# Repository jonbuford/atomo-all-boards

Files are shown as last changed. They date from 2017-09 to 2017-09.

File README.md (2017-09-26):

# atomo-all_boards
This is a collection of PCB designs for microcontroller development boards created for the Atomo line. We are releasing these files and designs to the world prior to our first production run. Any feedback on them is appreciated. 

Some basics:
1. We are releasing the raw design files and not the production silk screen with our commercial logo for Atomo. (We reserve the copyright on the Atomo brand.)
2. Yes, the refdes locations are on the parts for the most part. Earlier versions of the design attempted to keep all of the refdes markers in locations that could be used for silkscreen printing, but this required some very convoluted manual indications of what matches what. The density on these boards is just too high to have a clean 1:1 refdes printing on the boards. For the production silkscreens, we will be creating markings that is only for typical end use features and for major components or functional areas.
3. The 10-pin JTAG headers have been moved to the 26-pin/40-pin headers to reduce cost and to make all boards programmable using a Raspberry Pi or similar. 
4. Updated the 26-pin and 40-pin headers so that the pins are the same configuration for the first 26 pins. The 40-pin header is compatible with the ethernet adapter. 

So, this is the current state of the finished design files. To be added are the backplane and module files. The intent now is to try to move this into a more open development project to keep things growing. If you are interested in contributing, please contact the project.

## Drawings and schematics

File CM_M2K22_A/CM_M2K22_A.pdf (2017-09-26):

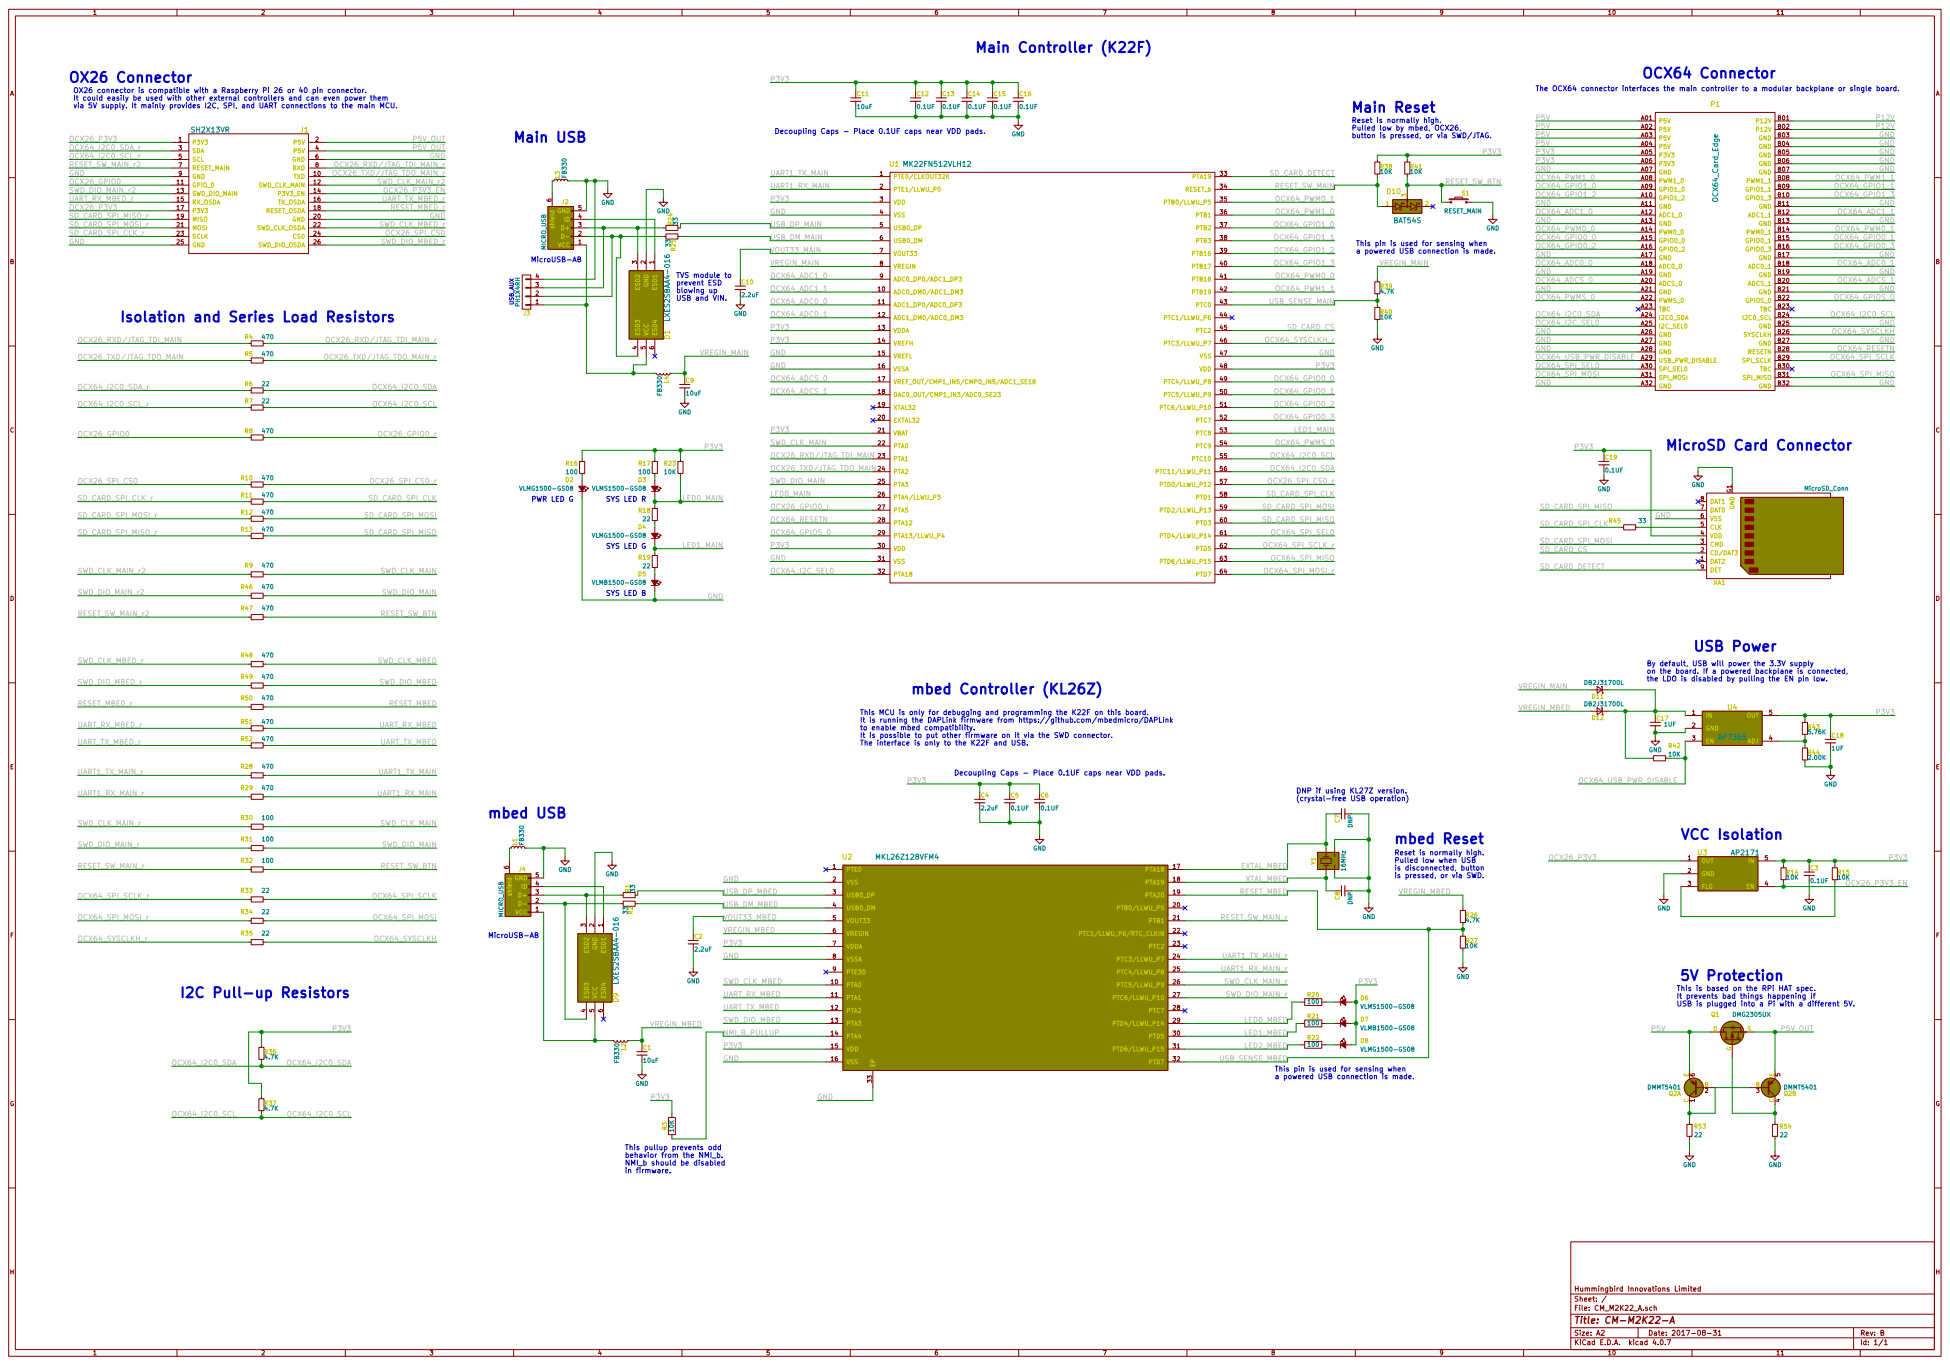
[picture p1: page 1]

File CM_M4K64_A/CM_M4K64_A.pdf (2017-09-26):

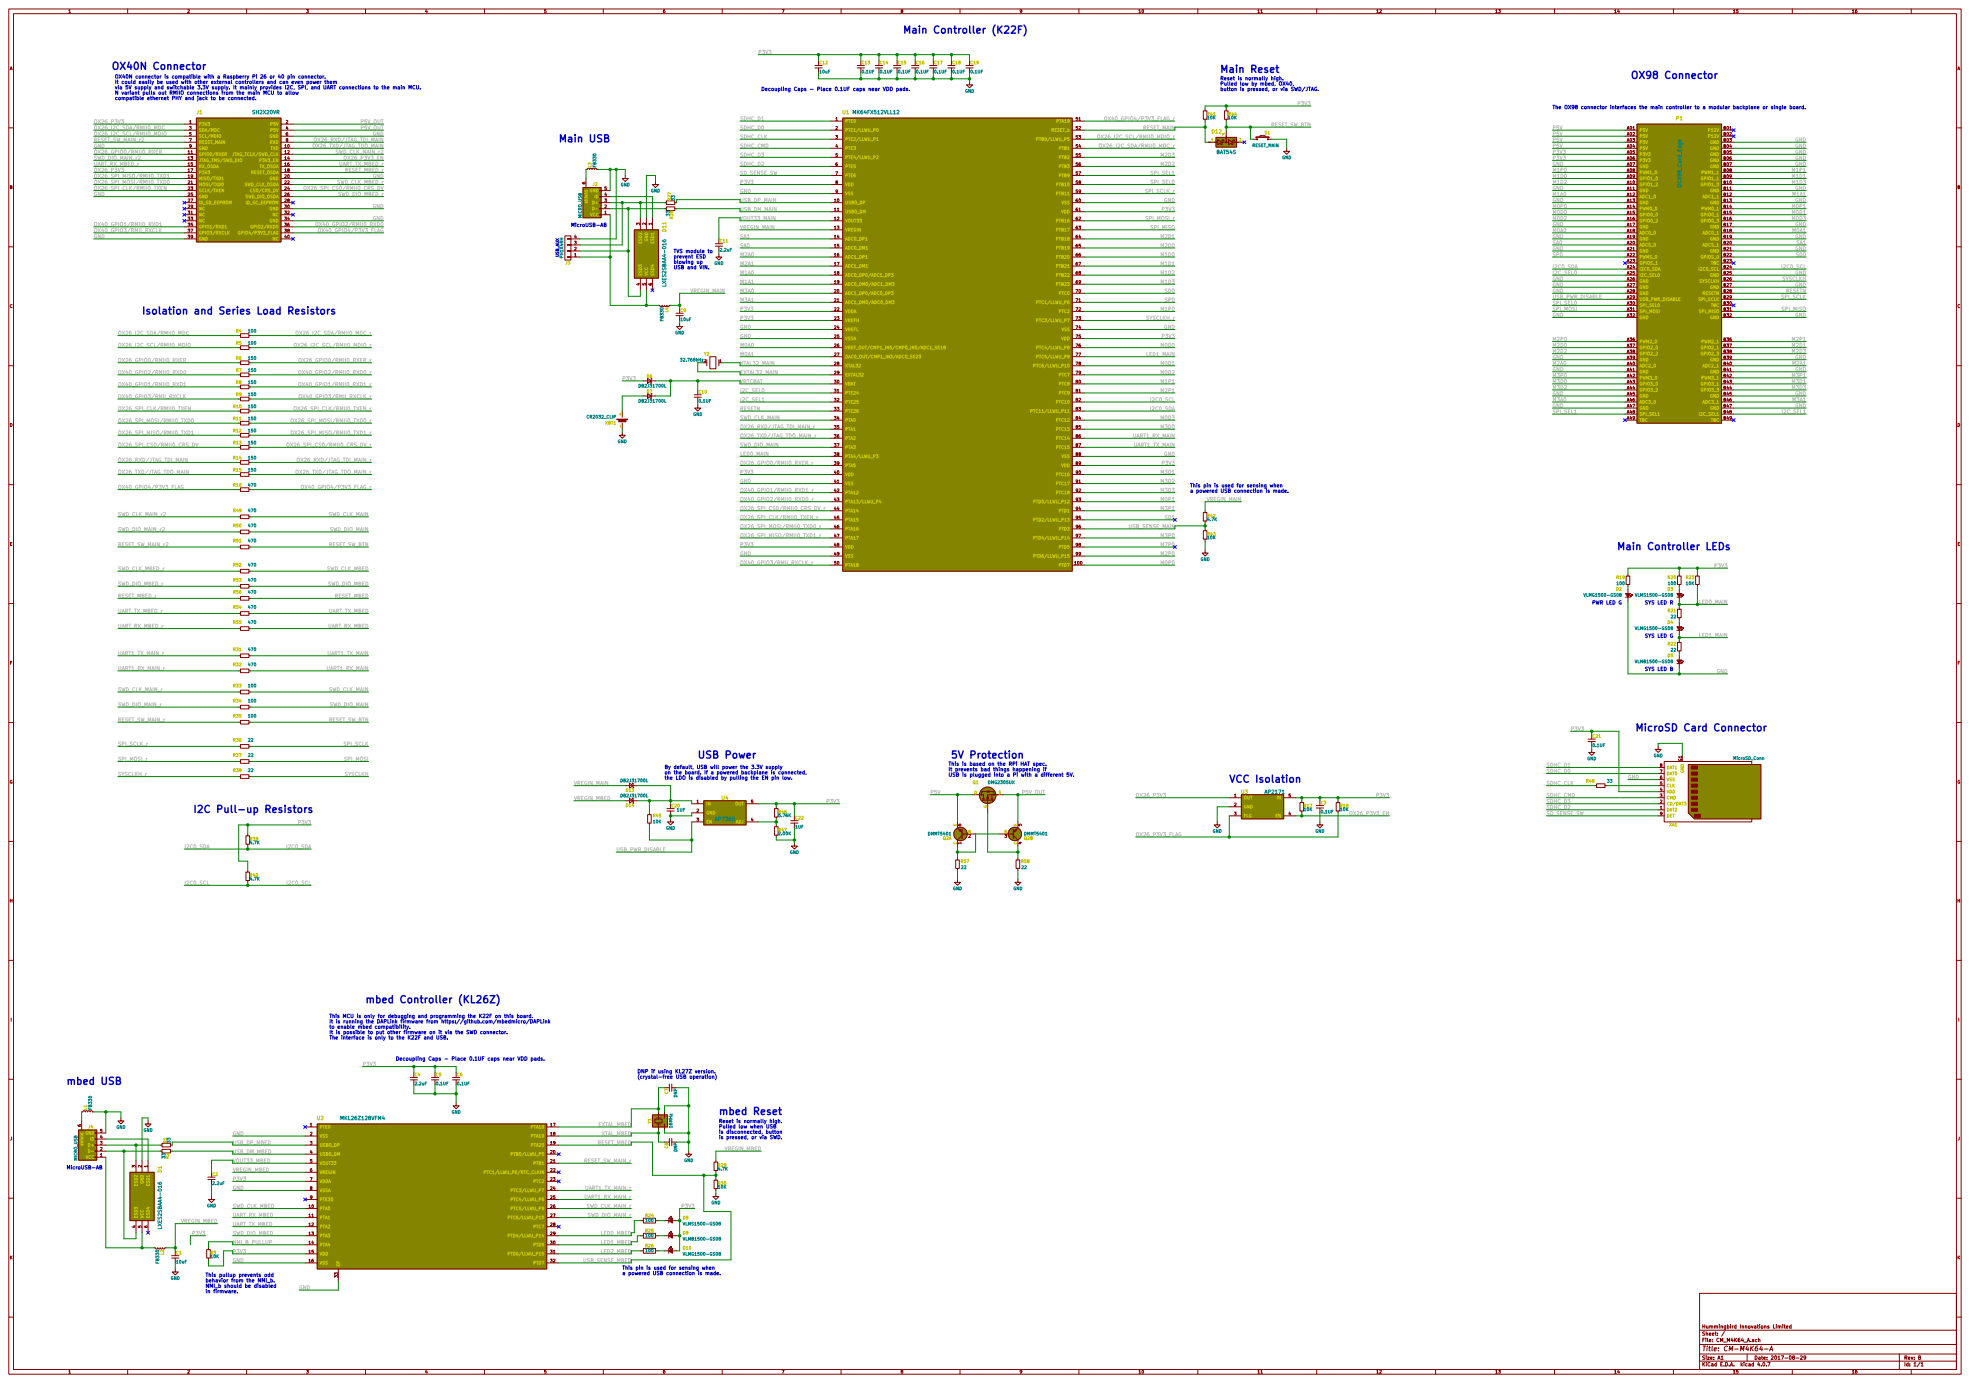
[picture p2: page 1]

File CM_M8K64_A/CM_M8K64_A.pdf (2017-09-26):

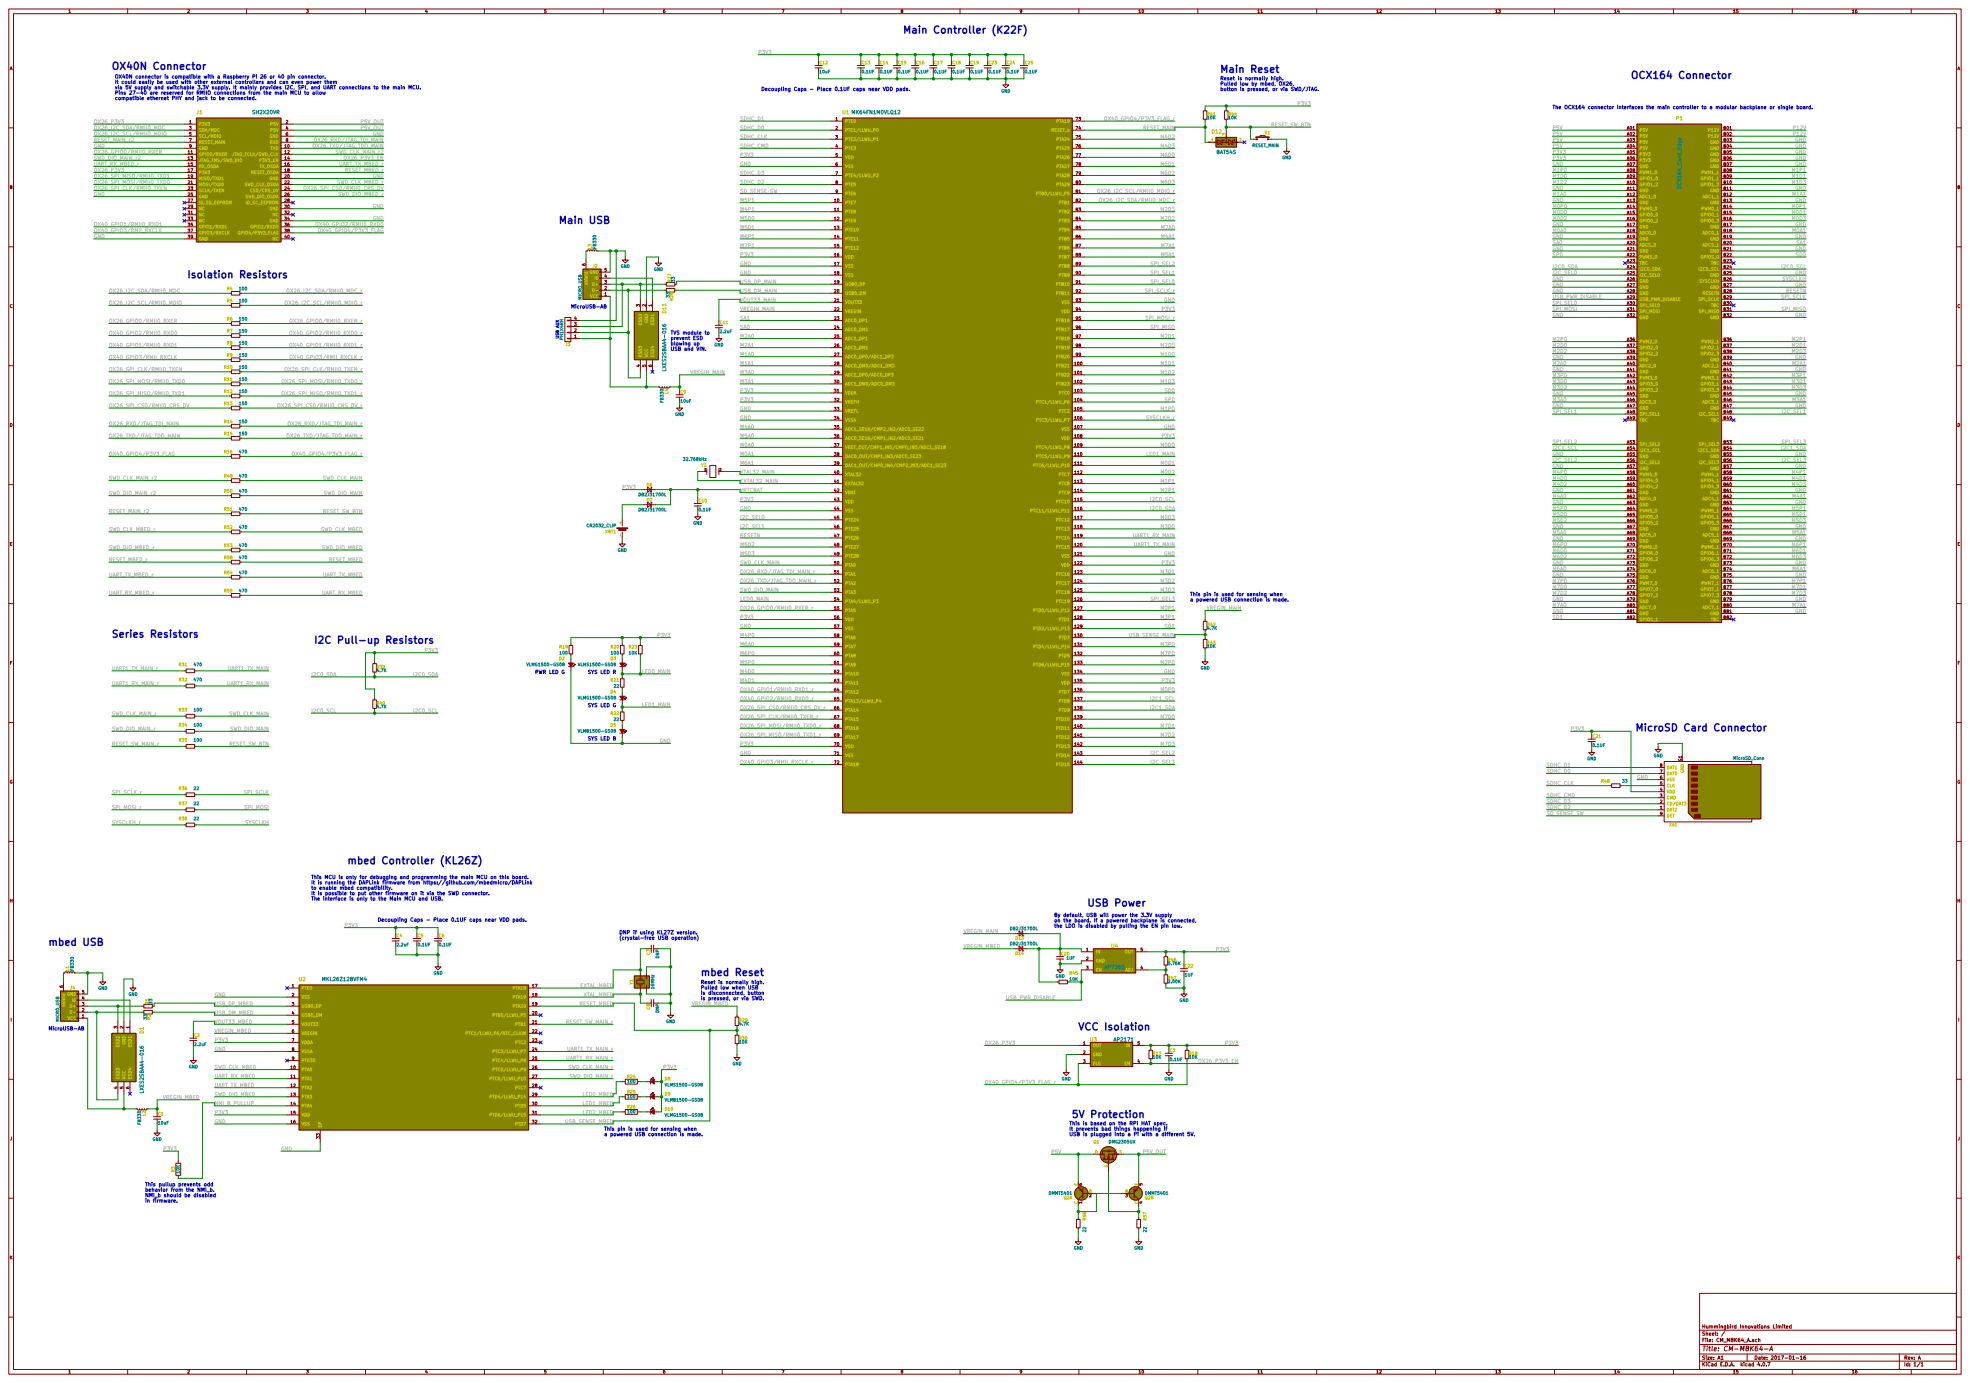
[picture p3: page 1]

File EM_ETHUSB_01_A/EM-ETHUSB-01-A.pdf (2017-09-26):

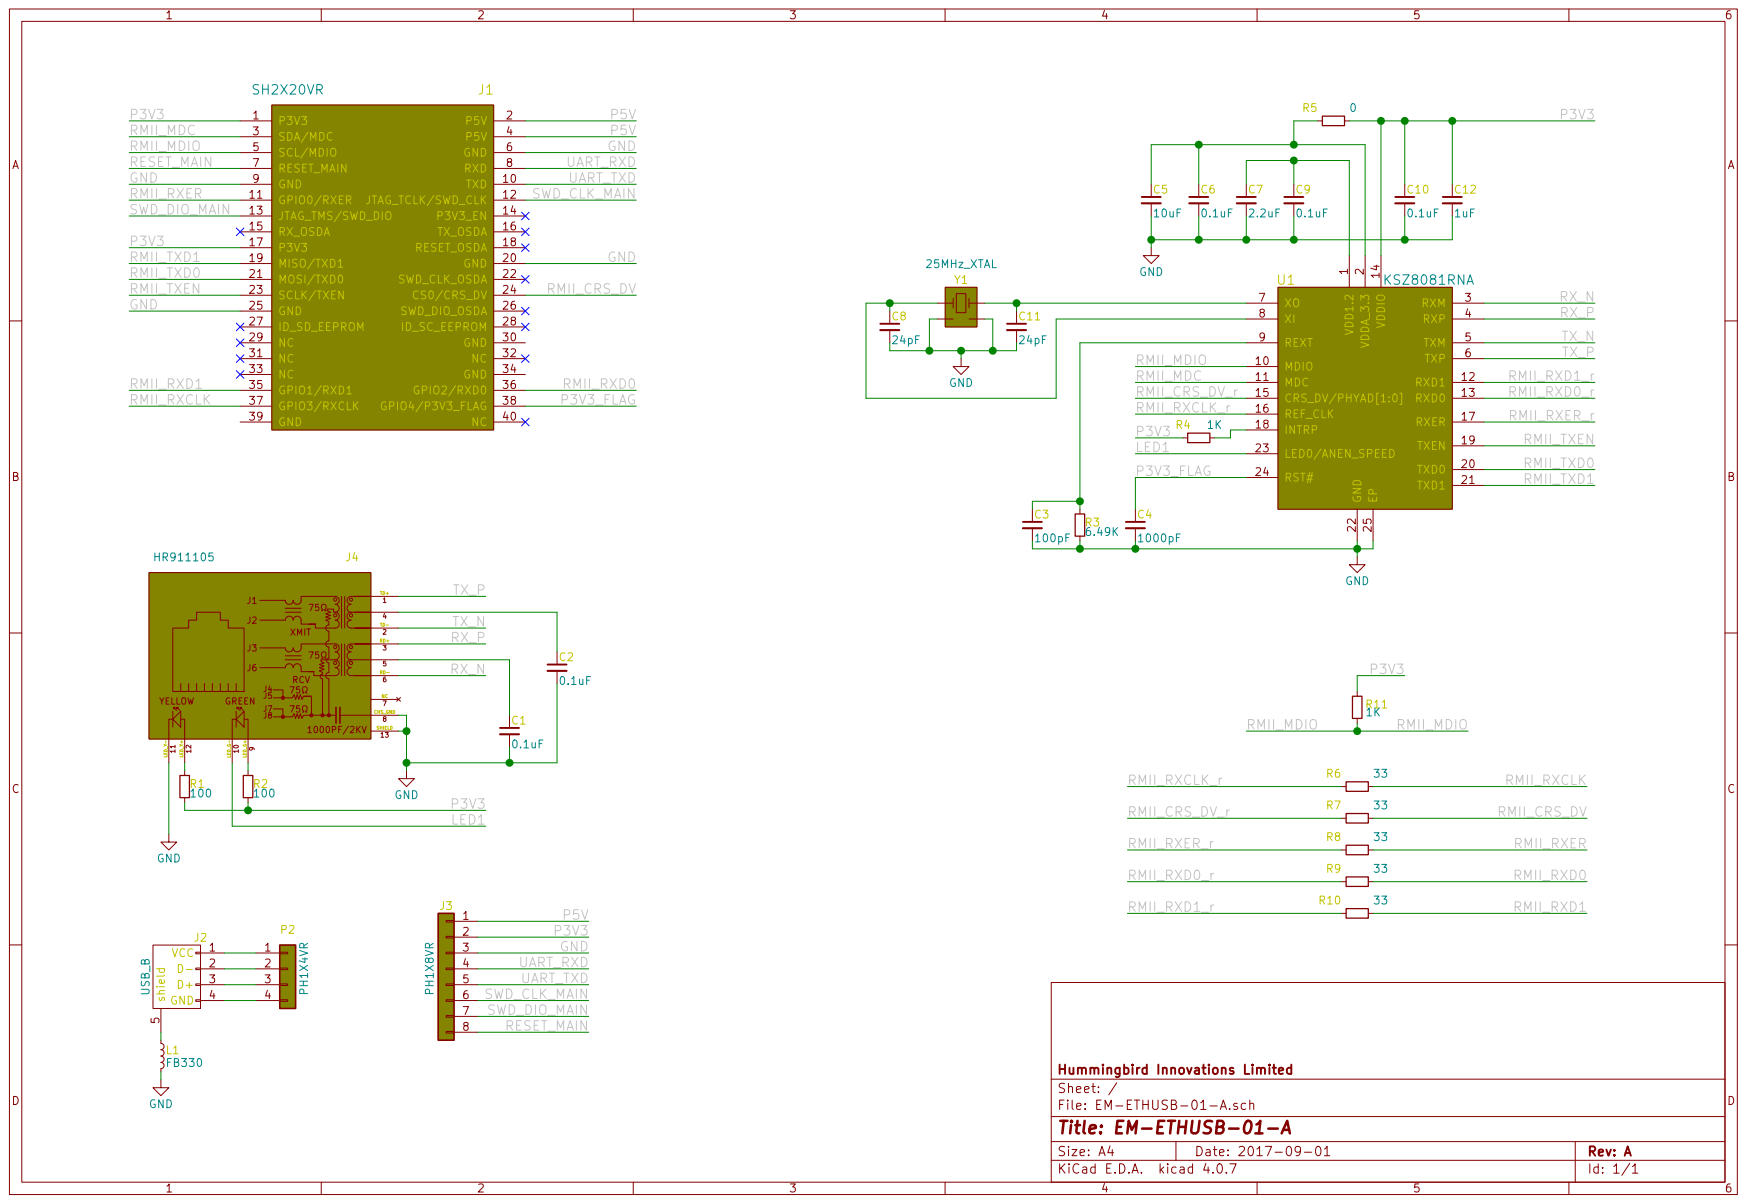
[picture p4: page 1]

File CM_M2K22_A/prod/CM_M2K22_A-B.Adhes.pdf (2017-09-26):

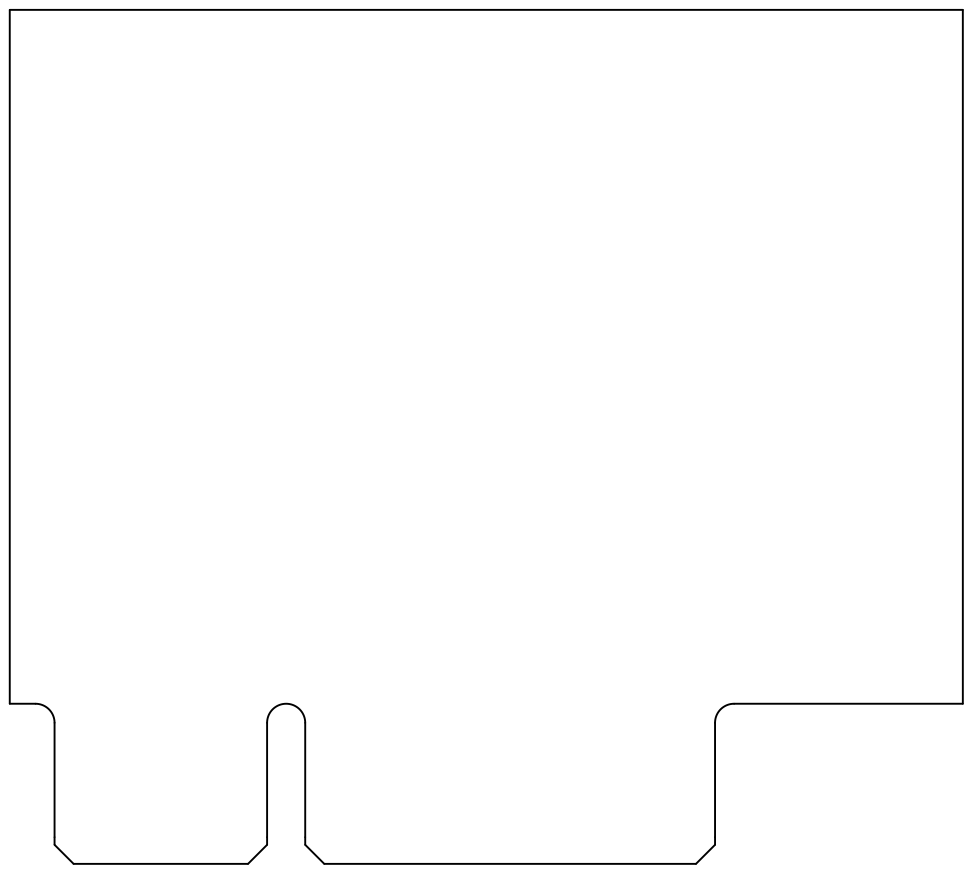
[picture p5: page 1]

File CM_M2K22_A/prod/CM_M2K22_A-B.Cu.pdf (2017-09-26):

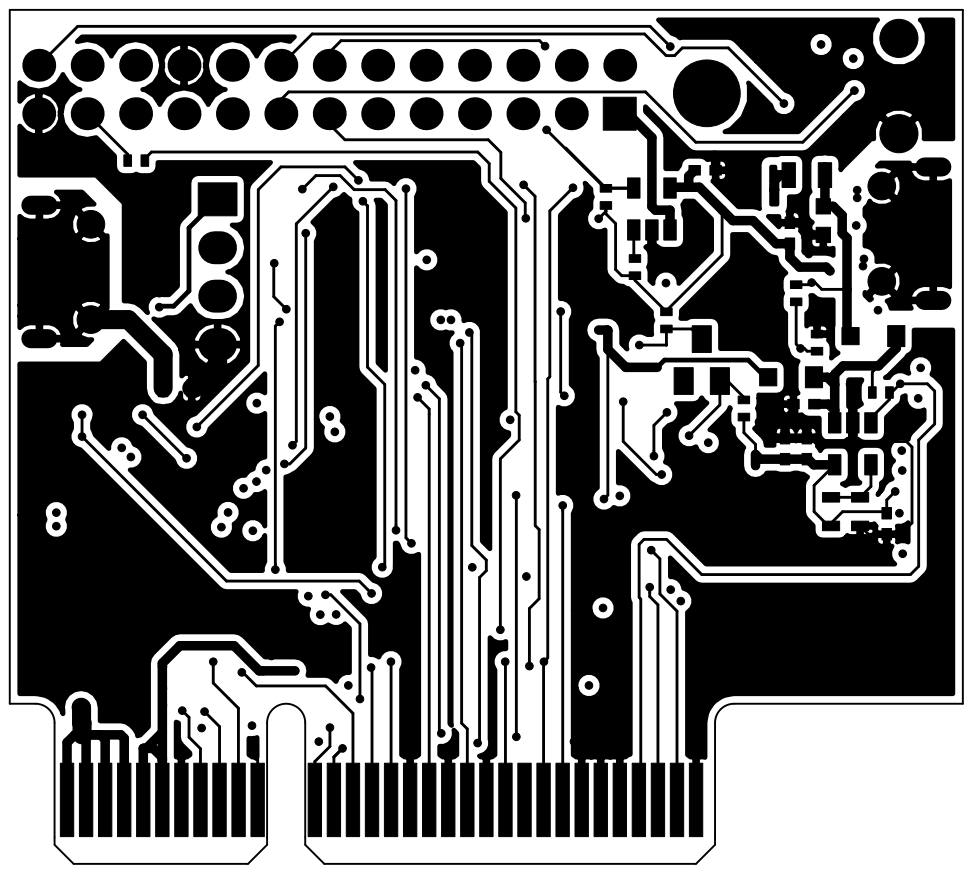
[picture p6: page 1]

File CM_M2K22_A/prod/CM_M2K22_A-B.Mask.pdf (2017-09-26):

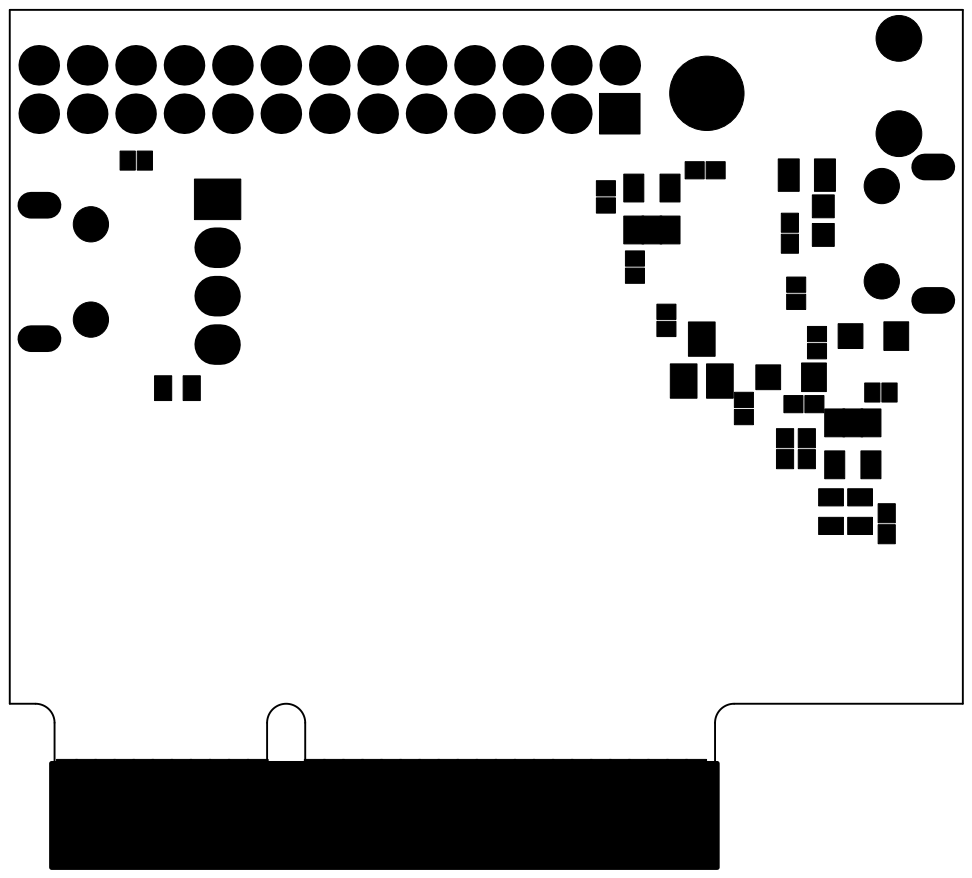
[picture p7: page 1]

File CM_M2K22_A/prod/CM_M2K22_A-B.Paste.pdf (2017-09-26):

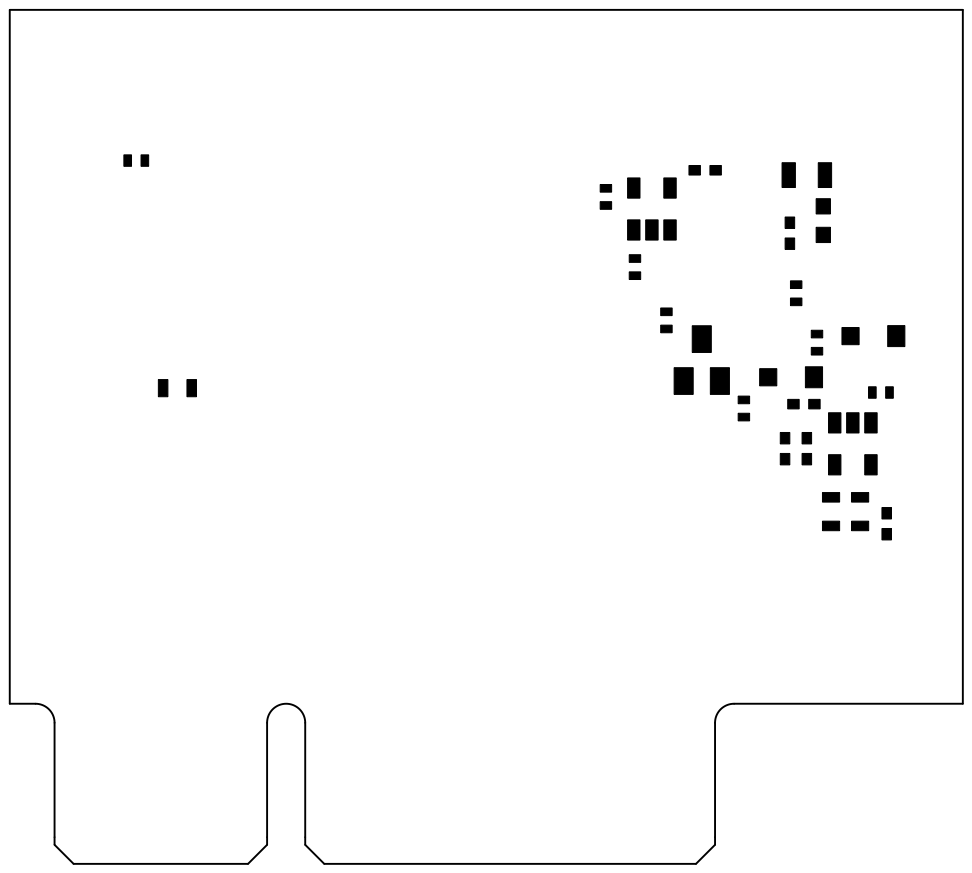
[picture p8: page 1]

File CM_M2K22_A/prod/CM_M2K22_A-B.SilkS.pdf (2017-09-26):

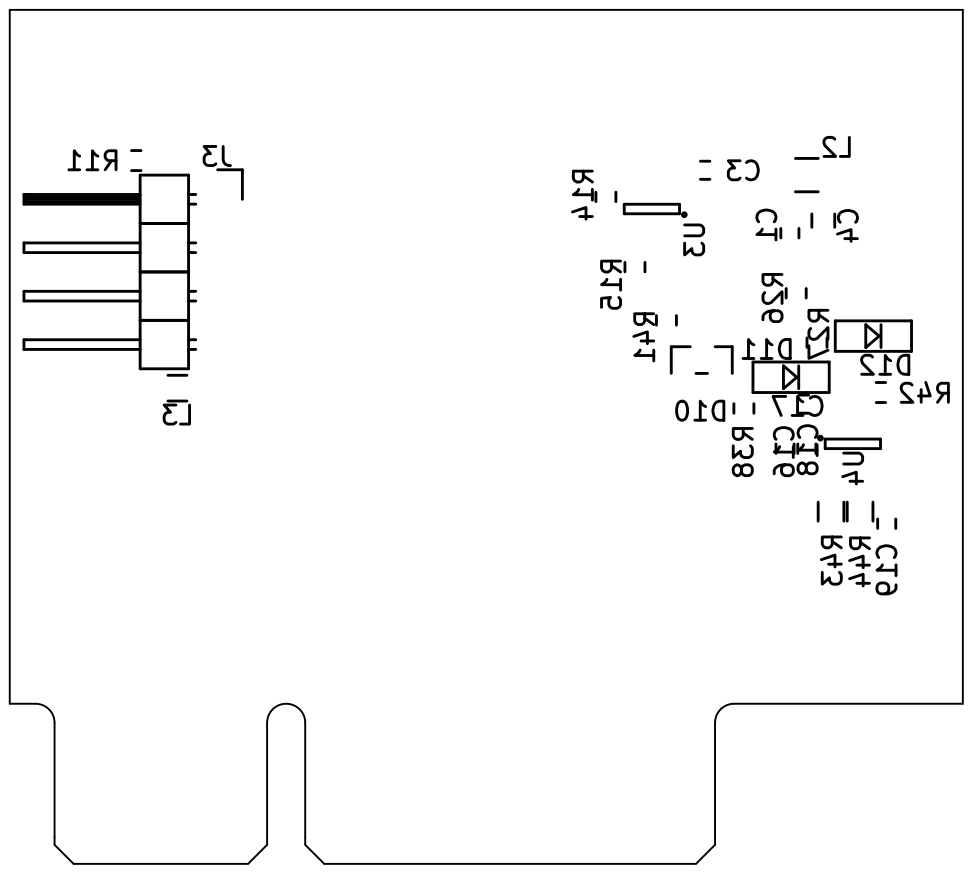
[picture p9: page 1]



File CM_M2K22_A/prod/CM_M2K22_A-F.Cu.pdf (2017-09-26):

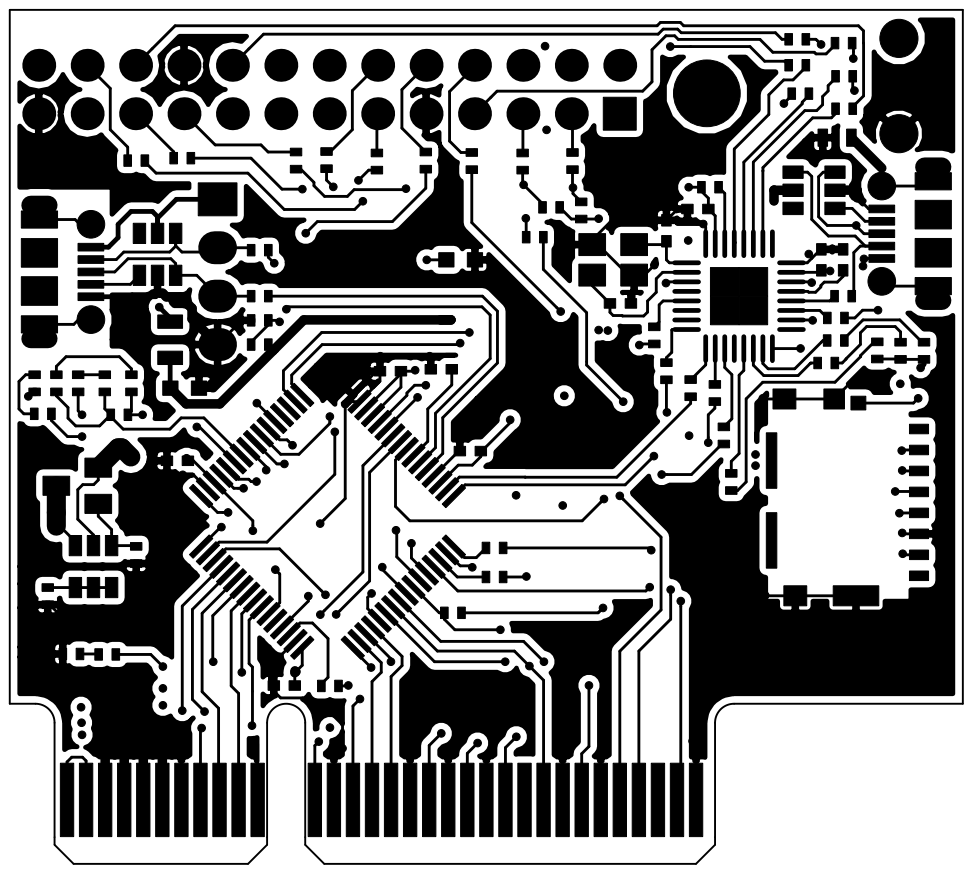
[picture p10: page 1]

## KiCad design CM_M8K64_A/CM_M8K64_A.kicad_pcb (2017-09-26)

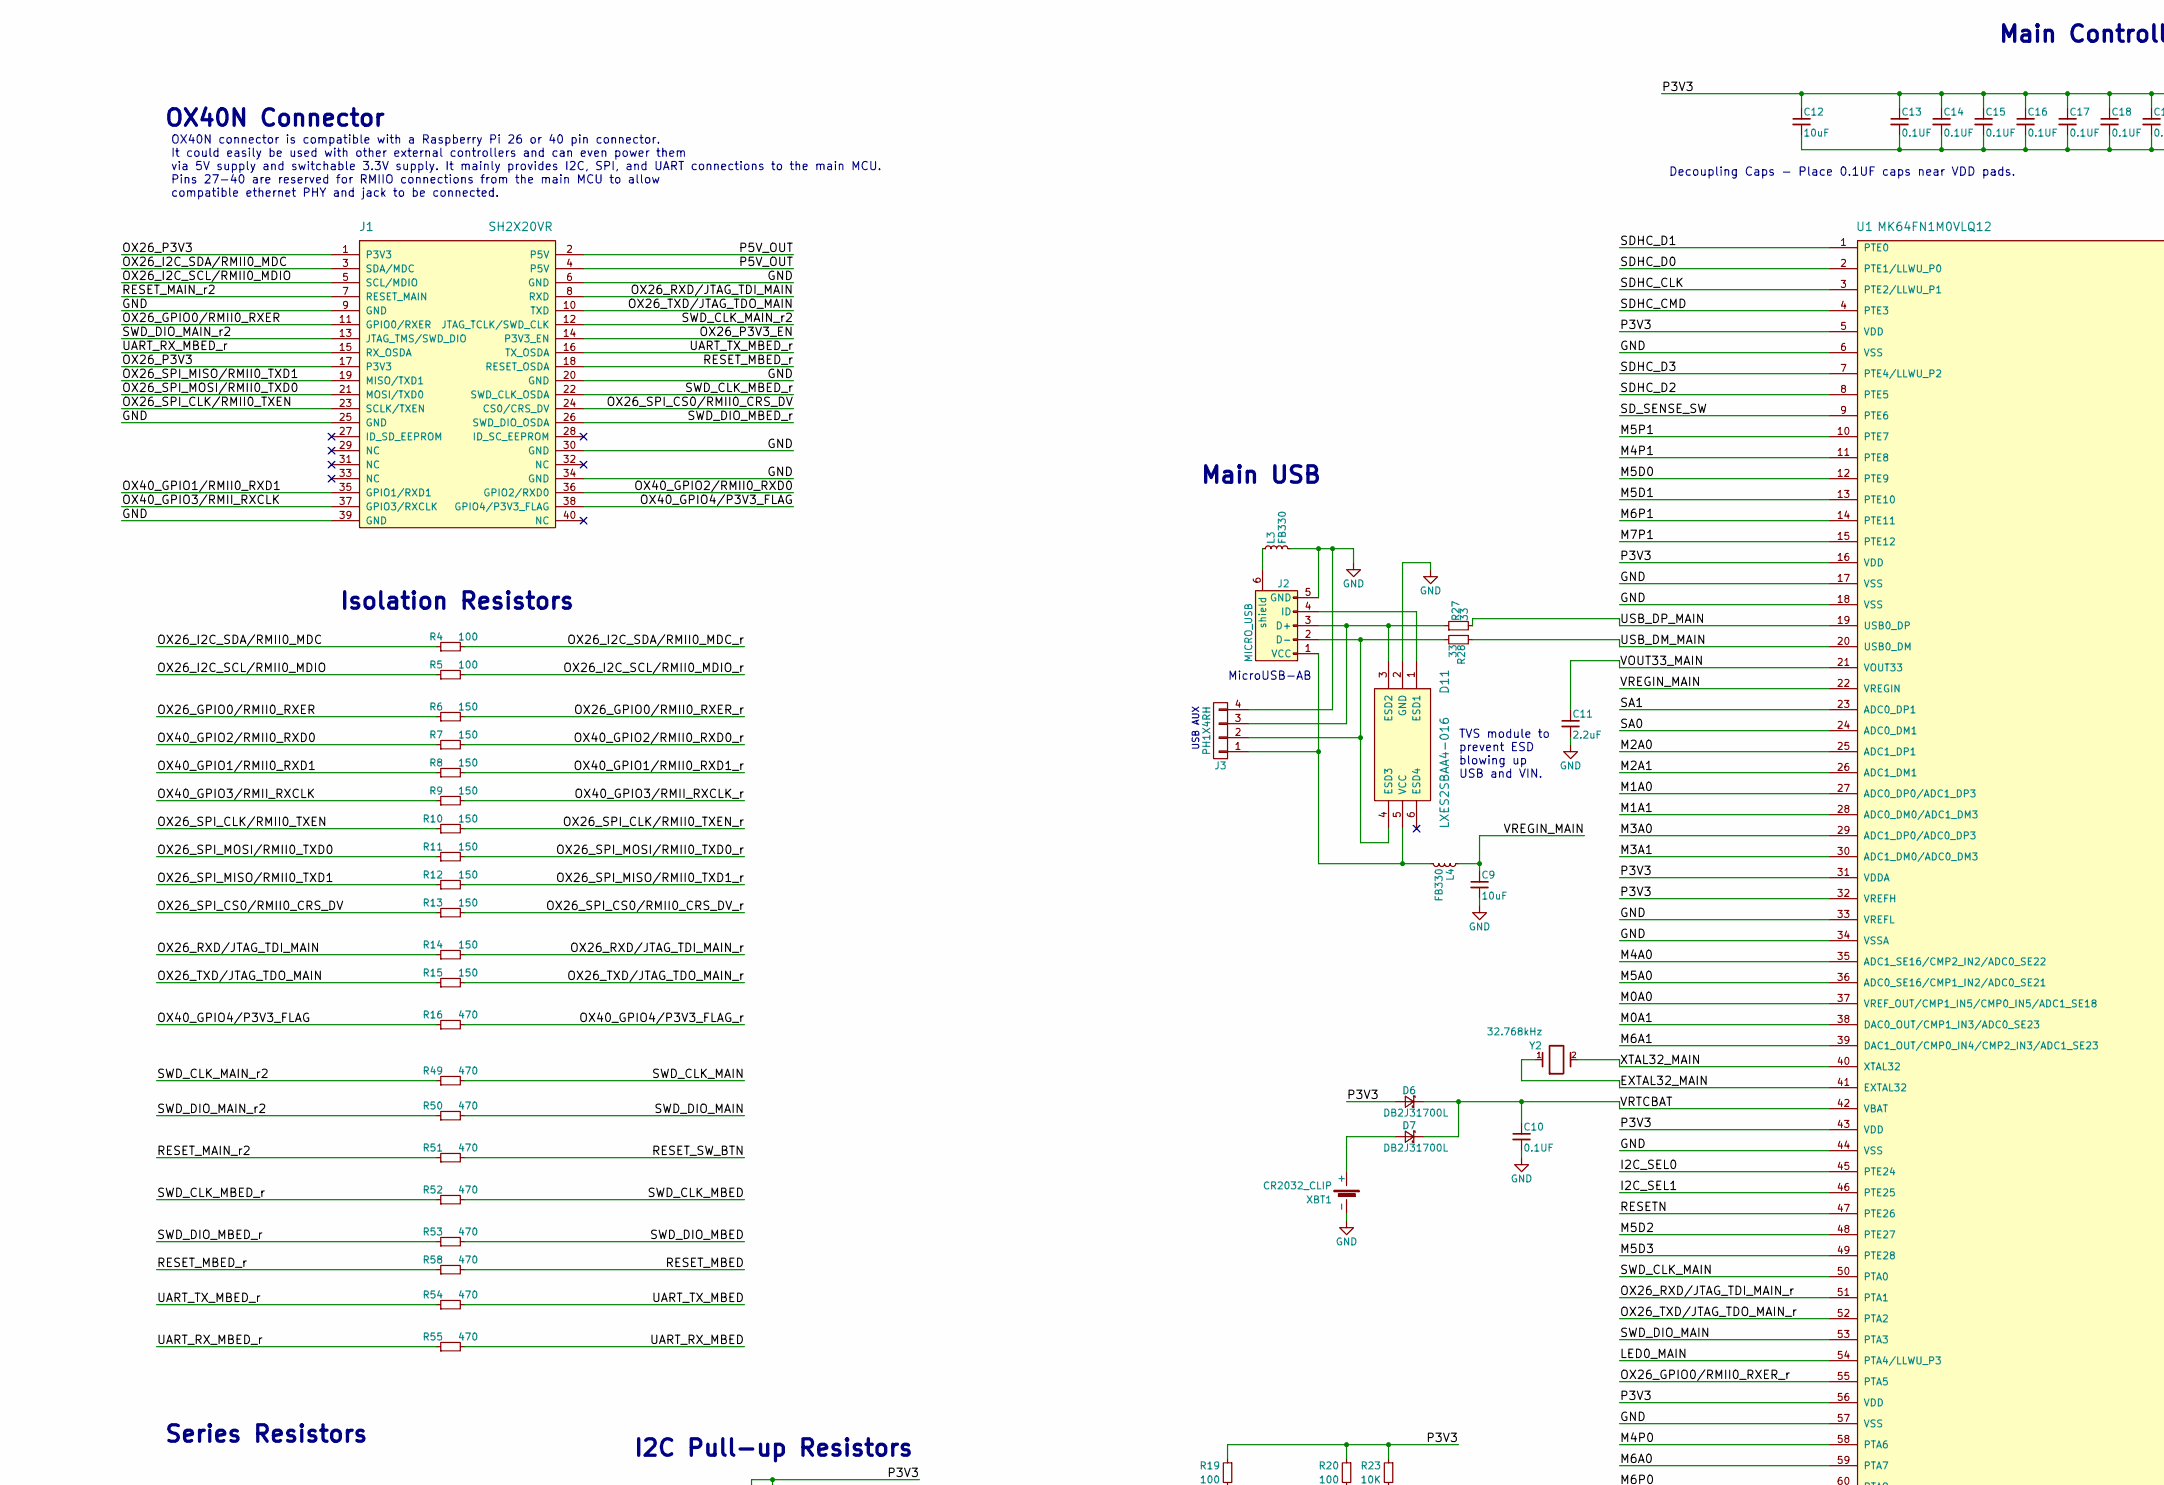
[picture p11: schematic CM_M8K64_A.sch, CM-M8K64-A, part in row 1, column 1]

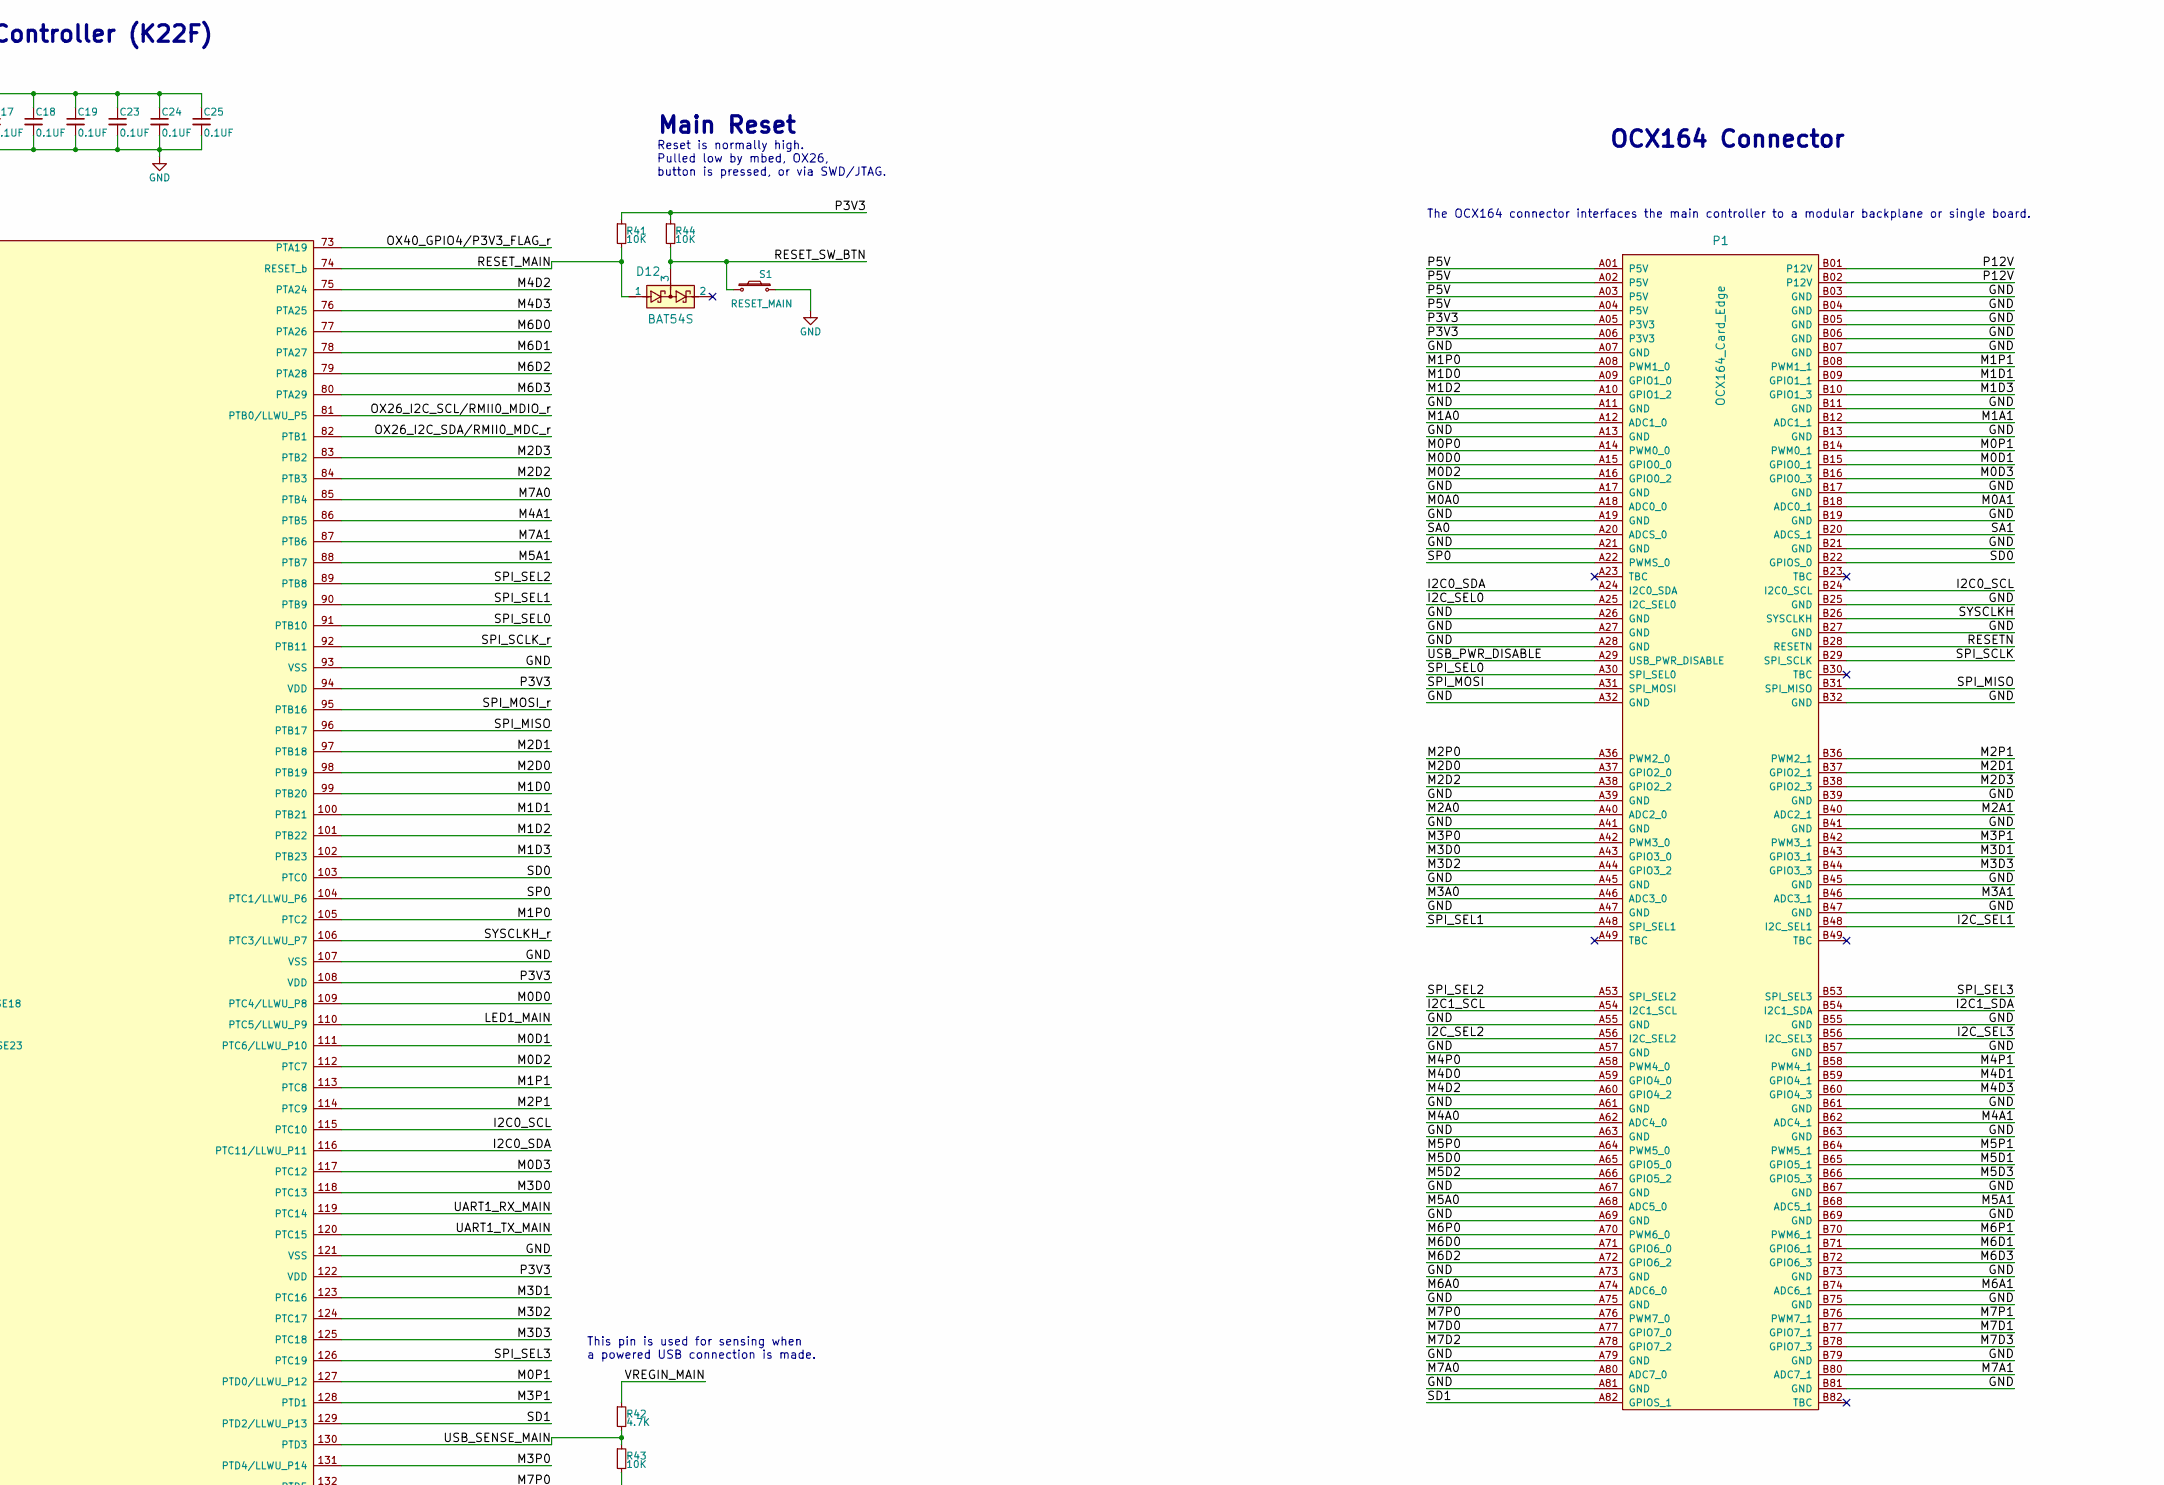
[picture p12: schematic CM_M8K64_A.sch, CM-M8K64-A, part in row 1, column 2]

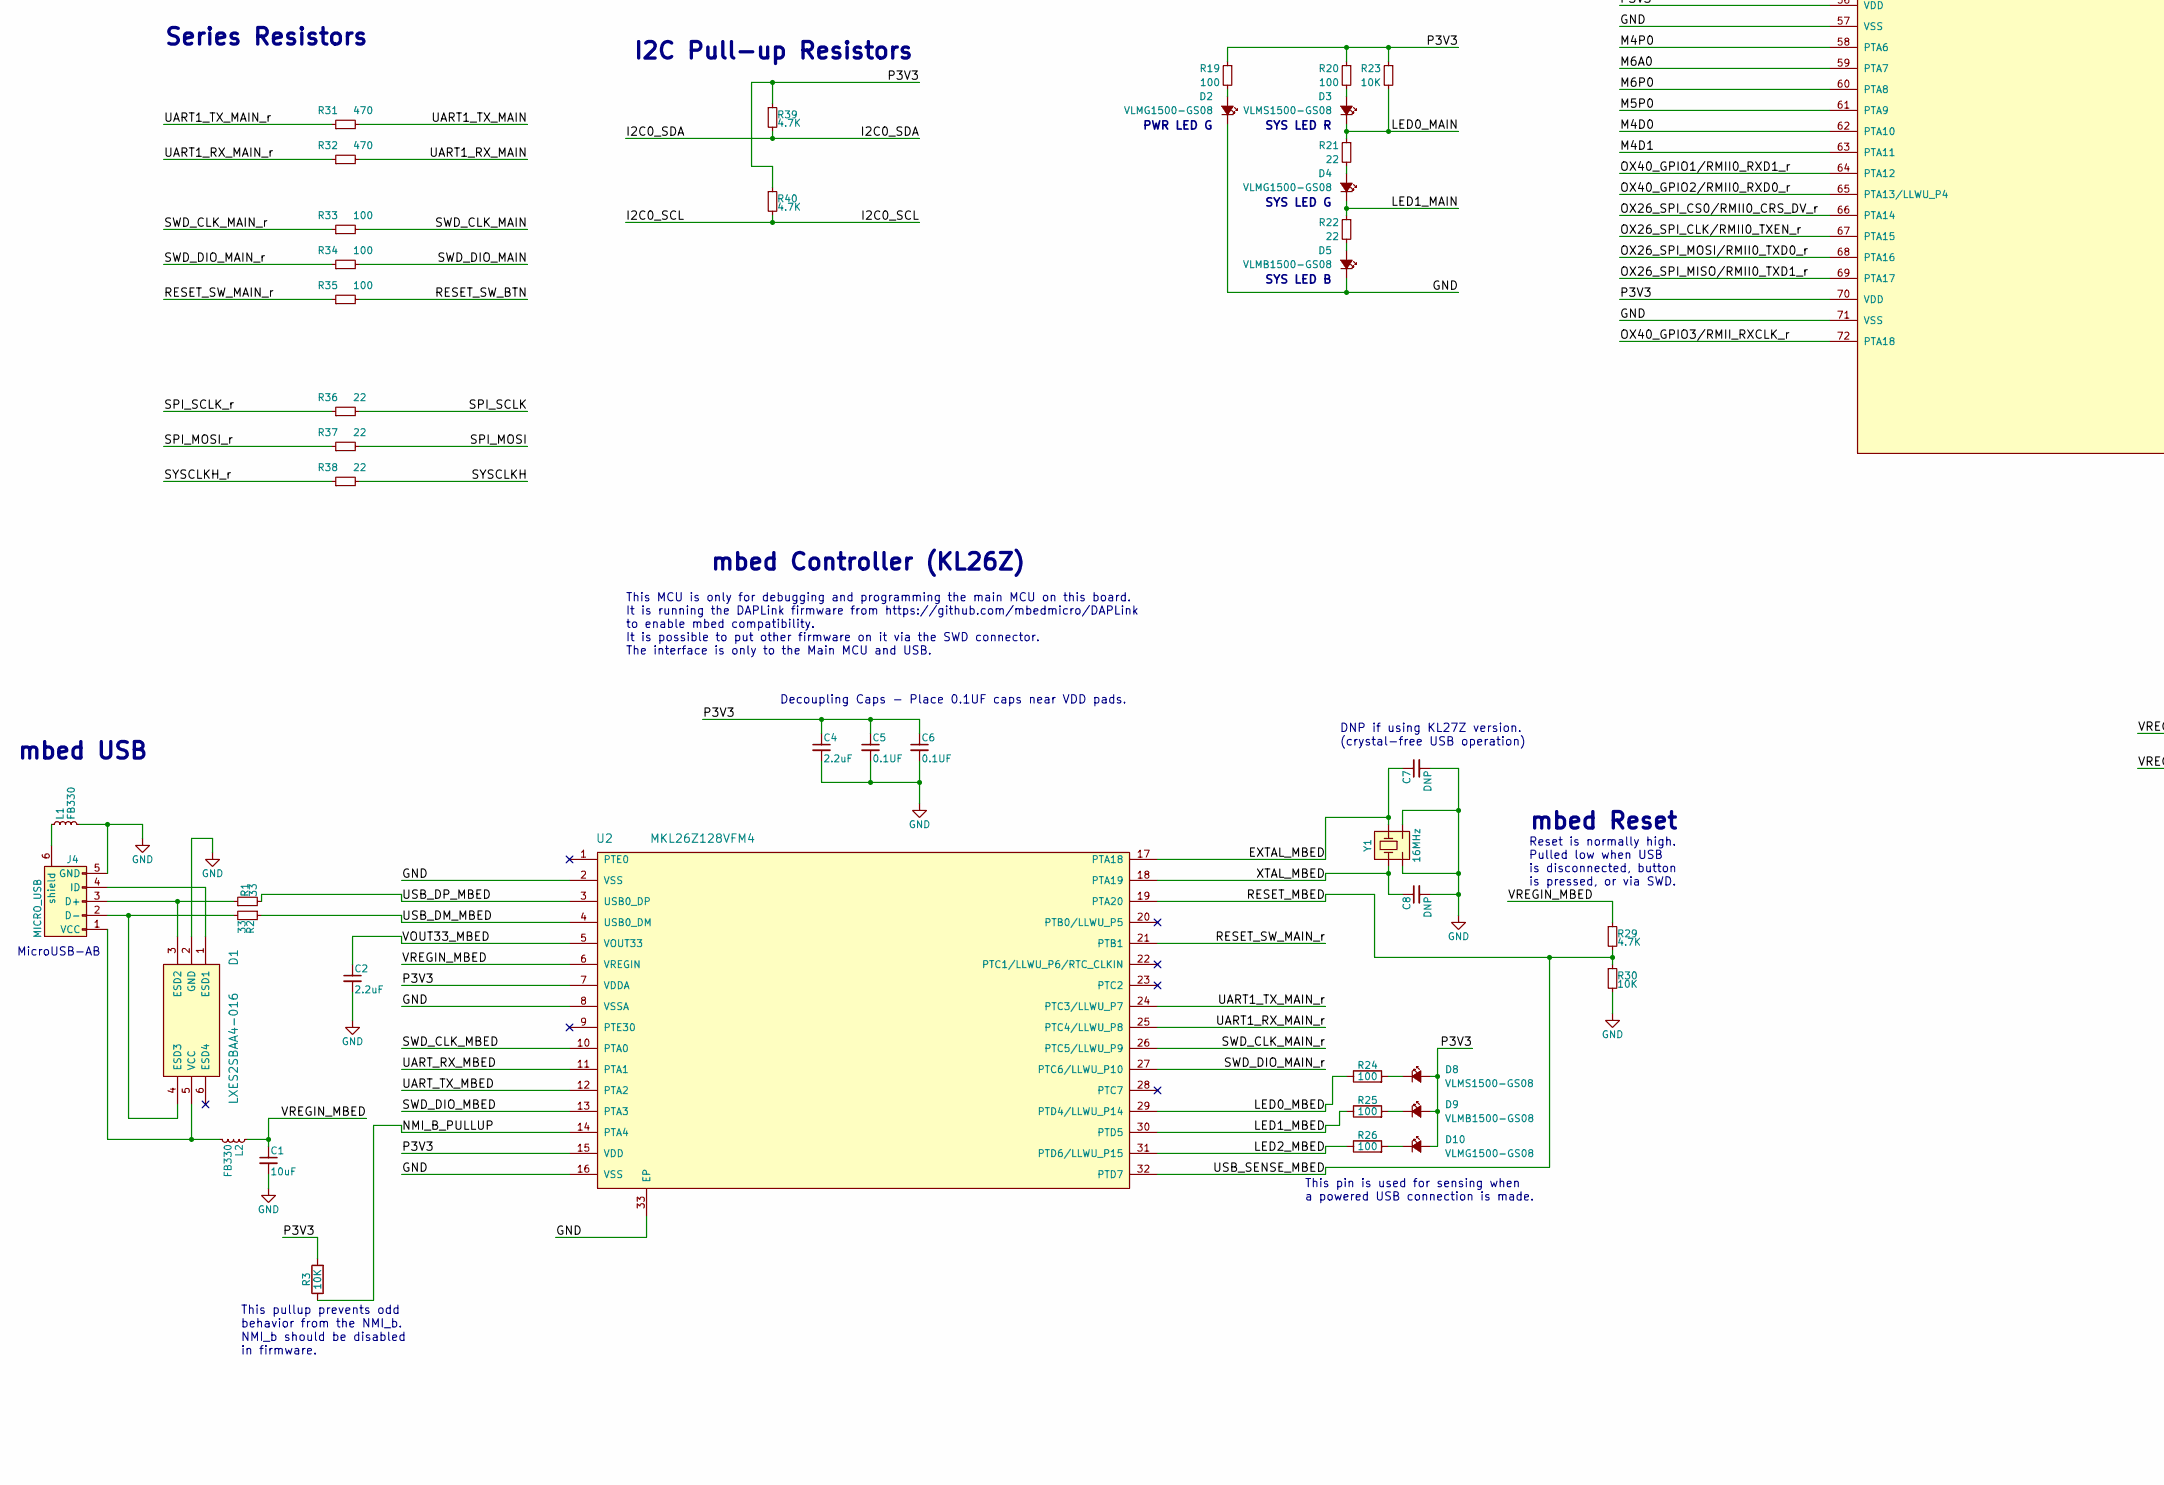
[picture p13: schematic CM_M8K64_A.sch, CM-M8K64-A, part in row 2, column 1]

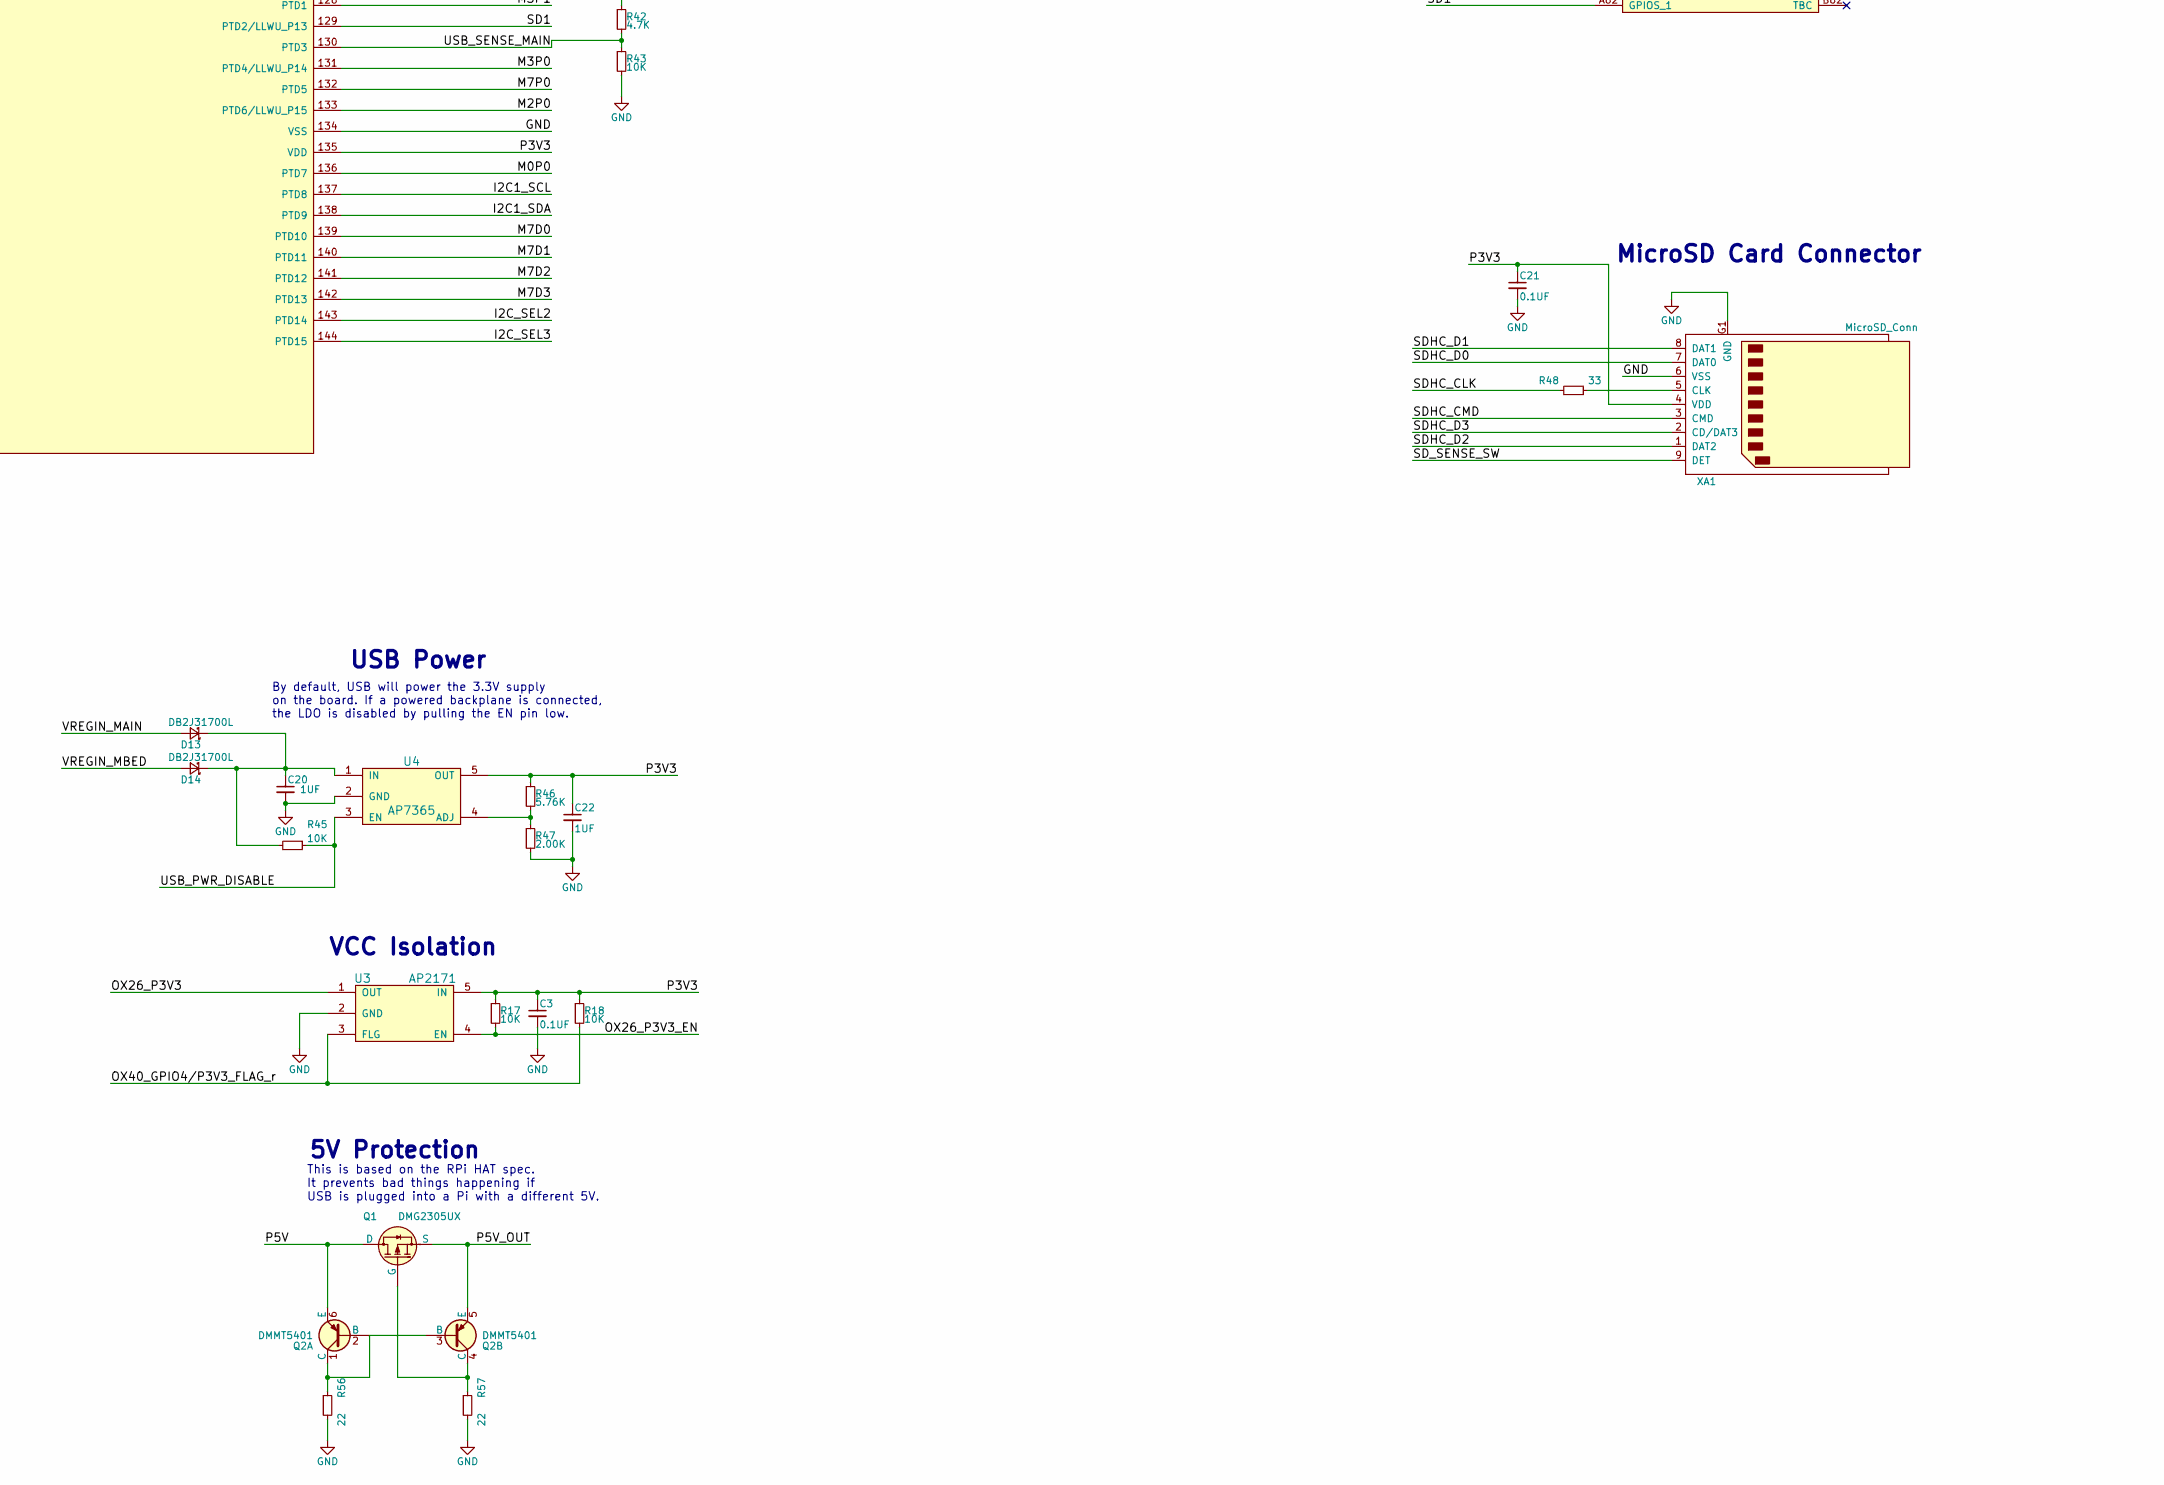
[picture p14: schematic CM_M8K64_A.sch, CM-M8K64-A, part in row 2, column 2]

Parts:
C1, C9, C12: 10uF; C_0603; MPN GRM188R60J106KE47D
C2, C4, C11: 2.2uF; C_0402; MPN GRM155R60J225KE95D
C3, C5, C6, C10, C13, C14, C15, C16, C17, C18, C19, C21, C23, C24, C25: 0.1UF; C_0402; MPN GRM155R71H104ME14D
C7, C8: DNP; C_0402; MPN DNP
C20, C22: 1UF; C_0402; MPN GRM155R60J105KE19D
D1, D11: LXES2SBAA4-016; SOT-23-6; MPN LXES2SBAA4-016
D2, D4, D10: VLMG1500-GS08; LED_0402; MPN VLMG1500-GS08
D3, D8: VLMS1500-GS08; LED_0402; MPN VLMS1500-GS08
D5, D9: VLMB1500-GS08; LED_0402; MPN VLMB1500-GS08
D6, D7, D13, D14: DB2J31700L; SC-90A; MPN DB2J31700L
D12: BAT54S; SOT-23; MPN BAT54S,215
J1: SH2X20VR; OX40_W_PI_HOLE; MPN PPPC202LFBN-RC
J2, J4: MICRO_USB; Micro_USB_Molex_105017-0001; MPN 1050170001
J3: PH1X4RH; Pin_Header_Angled_1x04; MPN DNP
L1, L3: FB330; R_0603; MPN MPZ1608S331ATA00
L2, L4: FB330; R_0805; MPN MPZ2012S331AT000
P1: OCX164_Card_Edge; MPN DNP
Q1: DMG2305UX; SOT-23; MPN DMG2305UX-13
Q2: DMMT5401; SOT-23-6; MPN DMMT5401-7-F
R1, R2, R27, R28, R48: 33; R_0402; MPN RC0402JR-0733RL
R3, R17, R18, R23, R30, R41, R43, R44, R45: 10K; R_0402; MPN RC0402JR-0710KL
R4, R5, R19, R20, R24, R25, R26, R33, R34, R35: 100; R_0402; MPN RC0402JR-07100RL
R6, R7, R8, R9, R10, R11, R12, R13, R14, R15: 150; R_0402; MPN RC0402JR-07150RL
R16, R31, R32, R49, R50, R51, R52, R53, R54, R55, R58: 470; R_0402; MPN RC0402JR-07470RL
R21, R22, R36, R37, R38, R56, R57: 22; R_0402; MPN RC0402JR-0722RL
R29, R39, R40, R42: 4.7K; R_0402; MPN RC0402JR-074K7L
R46: 5.76K; R_0603; Tolerance 1%; MPN RC0603FR-075K76L
R47: 2.00K; R_0603; Tolerance 1%; MPN RC0603FR-072KL
S1: RESET_MAIN; Switch_TS-1101F_SZ_BEST; MPN TS-1101F
U1: MK64FN1M0VLQ12; LQFP-144_20x20mm_Pitch0.5mm; MPN MK64FN1M0VLQ12
U2: MKL26Z128VFM4; QFN32_w_TP_FS; MPN MKL26Z128VFM4
U3: AP2171; SOT-23-5; MPN AP2171WG-7
U4: AP7365; SOT-23-5; MPN AP7365-WG-7
XA1: MicroSD_Conn; 1051620101; MPN 1051620101
XBT1: CR2032_CLIP; KEYSTONE_3034; MPN 3034TR
Y1: 16MHz; XTAL3_2X2_5; MPN FA-238 16.0000MB-K3
Y2: 32.768kHz; XTAL_CYL_CAN_SMT; MPN G33270007

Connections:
/EXTAL32_MAIN: U1.41 (EXTAL32), Y2.1
/EXTAL_MBED: C7.1, U2.17 (PTA18), Y1.1
/I2C0_SCL: P1.B24 (I2C0_SCL), R40.2, U1.115 (PTC10)
/I2C0_SDA: P1.A24 (I2C0_SDA), R39.2, U1.116 (PTC11/LLWU_P11)
/I2C1_SCL: P1.A54 (I2C1_SCL), U1.137 (PTD8)
/I2C1_SDA: P1.B54 (I2C1_SDA), U1.138 (PTD9)
/I2C_SEL0: P1.A25 (I2C_SEL0), U1.45 (PTE24)
/I2C_SEL1: P1.B48 (I2C_SEL1), U1.46 (PTE25)
/I2C_SEL2: P1.A56 (I2C_SEL2), U1.143 (PTD14)
/I2C_SEL3: P1.B56 (I2C_SEL3), U1.144 (PTD15)
/LED0_MAIN: D3.1 (K), R21.1, R23.2, U1.54 (PTA4/LLWU_P3)
/LED0_MBED: R24.1, U2.29 (PTD4/LLWU_P14)
/LED1_MAIN: D4.1 (K), R22.1, U1.110 (PTC5/LLWU_P9)
/LED1_MBED: R25.1, U2.30 (PTD5)
/LED2_MBED: R26.1, U2.31 (PTD6/LLWU_P15)
/M0A0: P1.A18 (ADC0_0), U1.37 (VREF_OUT/CMP1_IN5/CMP0_IN5/ADC1_SE18)
/M0A1: P1.B18 (ADC0_1), U1.38 (DAC0_OUT/CMP1_IN3/ADC0_SE23)
/M0D0: P1.A15 (GPIO0_0), U1.109 (PTC4/LLWU_P8)
/M0D1: P1.B15 (GPIO0_1), U1.111 (PTC6/LLWU_P10)
/M0D2: P1.A16 (GPIO0_2), U1.112 (PTC7)
/M0D3: P1.B16 (GPIO0_3), U1.117 (PTC12)
/M0P0: P1.A14 (PWM0_0), U1.136 (PTD7)
/M0P1: P1.B14 (PWM0_1), U1.127 (PTD0/LLWU_P12)
/M1A0: P1.A12 (ADC1_0), U1.27 (ADC0_DP0/ADC1_DP3)
/M1A1: P1.B12 (ADC1_1), U1.28 (ADC0_DM0/ADC1_DM3)
/M1D0: P1.A09 (GPIO1_0), U1.99 (PTB20)
/M1D1: P1.B09 (GPIO1_1), U1.100 (PTB21)
/M1D2: P1.A10 (GPIO1_2), U1.101 (PTB22)
/M1D3: P1.B10 (GPIO1_3), U1.102 (PTB23)
/M1P0: P1.A08 (PWM1_0), U1.105 (PTC2)
/M1P1: P1.B08 (PWM1_1), U1.113 (PTC8)
/M2A0: P1.A40 (ADC2_0), U1.25 (ADC1_DP1)
/M2A1: P1.B40 (ADC2_1), U1.26 (ADC1_DM1)
/M2D0: P1.A37 (GPIO2_0), U1.98 (PTB19)
/M2D1: P1.B37 (GPIO2_1), U1.97 (PTB18)
/M2D2: P1.A38 (GPIO2_2), U1.84 (PTB3)
/M2D3: P1.B38 (GPIO2_3), U1.83 (PTB2)
/M2P0: P1.A36 (PWM2_0), U1.133 (PTD6/LLWU_P15)
/M2P1: P1.B36 (PWM2_1), U1.114 (PTC9)
/M3A0: P1.A46 (ADC3_0), U1.29 (ADC1_DP0/ADC0_DP3)
/M3A1: P1.B46 (ADC3_1), U1.30 (ADC1_DM0/ADC0_DM3)
/M3D0: P1.A43 (GPIO3_0), U1.118 (PTC13)
/M3D1: P1.B43 (GPIO3_1), U1.123 (PTC16)
/M3D2: P1.A44 (GPIO3_2), U1.124 (PTC17)
/M3D3: P1.B44 (GPIO3_3), U1.125 (PTC18)
/M3P0: P1.A42 (PWM3_0), U1.131 (PTD4/LLWU_P14)
/M3P1: P1.B42 (PWM3_1), U1.128 (PTD1)
/M4A0: P1.A62 (ADC4_0), U1.35 (ADC1_SE16/CMP2_IN2/ADC0_SE22)
/M4A1: P1.B62 (ADC4_1), U1.86 (PTB5)
/M4D0: P1.A59 (GPIO4_0), U1.62 (PTA10)
/M4D1: P1.B59 (GPIO4_1), U1.63 (PTA11)
/M4D2: P1.A60 (GPIO4_2), U1.75 (PTA24)
/M4D3: P1.B60 (GPIO4_3), U1.76 (PTA25)
/M4P0: P1.A58 (PWM4_0), U1.58 (PTA6)
/M4P1: P1.B58 (PWM4_1), U1.11 (PTE8)
/M5A0: P1.A68 (ADC5_0), U1.36 (ADC0_SE16/CMP1_IN2/ADC0_SE21)
/M5A1: P1.B68 (ADC5_1), U1.88 (PTB7)
/M5D0: P1.A65 (GPIO5_0), U1.12 (PTE9)
/M5D1: P1.B65 (GPIO5_1), U1.13 (PTE10)
/M5D2: P1.A66 (GPIO5_2), U1.48 (PTE27)
/M5D3: P1.B66 (GPIO5_3), U1.49 (PTE28)
/M5P0: P1.A64 (PWM5_0), U1.61 (PTA9)
/M5P1: P1.B64 (PWM5_1), U1.10 (PTE7)
/M6A0: P1.A74 (ADC6_0), U1.59 (PTA7)
/M6A1: P1.B74 (ADC6_1), U1.39 (DAC1_OUT/CMP0_IN4/CMP2_IN3/ADC1_SE23)
/M6D0: P1.A71 (GPIO6_0), U1.77 (PTA26)
/M6D1: P1.B71 (GPIO6_1), U1.78 (PTA27)
/M6D2: P1.A72 (GPIO6_2), U1.79 (PTA28)
/M6D3: P1.B72 (GPIO6_3), U1.80 (PTA29)
/M6P0: P1.A70 (PWM6_0), U1.60 (PTA8)
/M6P1: P1.B70 (PWM6_1), U1.14 (PTE11)
/M7A0: P1.A80 (ADC7_0), U1.85 (PTB4)
/M7A1: P1.B80 (ADC7_1), U1.87 (PTB6)
/M7D0: P1.A77 (GPIO7_0), U1.139 (PTD10)
/M7D1: P1.B77 (GPIO7_1), U1.140 (PTD11)
/M7D2: P1.A78 (GPIO7_2), U1.141 (PTD12)
/M7D3: P1.B78 (GPIO7_3), U1.142 (PTD13)
/M7P0: P1.A76 (PWM7_0), U1.132 (PTD5)
/M7P1: P1.B76 (PWM7_1), U1.15 (PTE12)
/NMI_B_PULLUP: R3.1, U2.14 (PTA4)
/OX26_GPIO0/RMII0_RXER: J1.11 (GPIO0/RXER), R6.1
/OX26_GPIO0/RMII0_RXER_r: R6.2, U1.55 (PTA5)
/OX26_I2C_SCL/RMII0_MDIO: J1.5 (SCL/MDIO), R5.1
/OX26_I2C_SCL/RMII0_MDIO_r: R5.2, U1.81 (PTB0/LLWU_P5)
/OX26_I2C_SDA/RMII0_MDC: J1.3 (SDA/MDC), R4.1
/OX26_I2C_SDA/RMII0_MDC_r: R4.2, U1.82 (PTB1)
/OX26_P3V3: J1.1 (P3V3), J1.17 (P3V3), U3.1 (OUT)
/OX26_P3V3_EN: J1.14 (P3V3_EN), R17.2, U3.4 (EN)
/OX26_RXD/JTAG_TDI_MAIN: J1.8 (RXD), R14.1
/OX26_RXD/JTAG_TDI_MAIN_r: R14.2, U1.51 (PTA1)
/OX26_SPI_CLK/RMII0_TXEN: J1.23 (SCLK/TXEN), R10.1
/OX26_SPI_CLK/RMII0_TXEN_r: R10.2, U1.67 (PTA15)
/OX26_SPI_CS0/RMII0_CRS_DV: J1.24 (CS0/CRS_DV), R13.1
/OX26_SPI_CS0/RMII0_CRS_DV_r: R13.2, U1.66 (PTA14)
/OX26_SPI_MISO/RMII0_TXD1: J1.19 (MISO/TXD1), R12.1
/OX26_SPI_MISO/RMII0_TXD1_r: R12.2, U1.69 (PTA17)
/OX26_SPI_MOSI/RMII0_TXD0: J1.21 (MOSI/TXD0), R11.1
/OX26_SPI_MOSI/RMII0_TXD0_r: R11.2, U1.68 (PTA16)
/OX26_TXD/JTAG_TDO_MAIN: J1.10 (TXD), R15.1
/OX26_TXD/JTAG_TDO_MAIN_r: R15.2, U1.52 (PTA2)
/OX40_GPIO1/RMII0_RXD1: J1.35 (GPIO1/RXD1), R8.1
/OX40_GPIO1/RMII0_RXD1_r: R8.2, U1.64 (PTA12)
/OX40_GPIO2/RMII0_RXD0: J1.36 (GPIO2/RXD0), R7.1
/OX40_GPIO2/RMII0_RXD0_r: R7.2, U1.65 (PTA13/LLWU_P4)
/OX40_GPIO3/RMII_RXCLK: J1.37 (GPIO3/RXCLK), R9.1
/OX40_GPIO3/RMII_RXCLK_r: R9.2, U1.72 (PTA18)
/OX40_GPIO4/P3V3_FLAG: J1.38 (GPIO4/P3V3_FLAG), R16.1
/OX40_GPIO4/P3V3_FLAG_r: R16.2, R18.2, U1.73 (PTA19), U3.3 (FLG)
/P3V3: C3.1, C4.1, C5.1, C6.1, C12.1, C13.1, C14.1, C15.1, C16.1, C17.1, C18.1, C19.1, C21.1, C22.1, C23.1, C24.1, C25.1, D6.2 (A), D8.2 (A), D9.2 (A), D10.2 (A), P1.A05 (P3V3), P1.A06 (P3V3), R3.2, R17.1, R18.1, R19.1, R20.1, R23.1, R39.1, R40.1, R41.1, R44.1, R46.1, U1.5 (VDD), U1.16 (VDD), U1.31 (VDDA), U1.32 (VREFH), U1.43 (VDD), U1.56 (VDD), U1.70 (VDD), U1.94 (VDD), U1.108 (VDD), U1.122 (VDD), U1.135 (VDD), U2.7 (VDDA), U2.15 (VDD), U3.5 (IN), U4.5 (OUT), XA1.4 (VDD)
/P5V: P1.A01 (P5V), P1.A02 (P5V), P1.A03 (P5V), P1.A04 (P5V), Q1.3 (D), Q2.6 (E)
/P5V_OUT: J1.2 (P5V), J1.4 (P5V), Q1.2 (S), Q2.5 (E)
/P12V: P1.B01 (P12V), P1.B02 (P12V)
/RESETN: P1.B28 (RESETN), U1.47 (PTE26)
/RESET_MAIN: D12.1, R41.2, U1.74 (RESET_b)
/RESET_MAIN_r2: J1.7 (RESET_MAIN), R51.1
/RESET_MBED: R29.2, R30.1, R58.2, U2.19 (PTA20), U2.32 (PTD7)
/RESET_MBED_r: J1.18 (RESET_OSDA), R58.1
/RESET_SW_BTN: D12.3, R35.2, R44.2, R51.2, S1.1
/RESET_SW_MAIN_r: R35.1, U2.21 (PTB1)
/SA0: P1.A20 (ADCS_0), U1.24 (ADC0_DM1)
/SA1: P1.B20 (ADCS_1), U1.23 (ADC0_DP1)
/SD0: P1.B22 (GPIOS_0), U1.103 (PTC0)
/SD1: P1.A82 (GPIOS_1), U1.129 (PTD2/LLWU_P13)
/SDHC_CLK: R48.2, U1.3 (PTE2/LLWU_P1)
/SDHC_CMD: U1.4 (PTE3), XA1.3 (CMD)
/SDHC_D0: U1.2 (PTE1/LLWU_P0), XA1.7 (DAT0)
/SDHC_D1: U1.1 (PTE0), XA1.8 (DAT1)
/SDHC_D2: U1.8 (PTE5), XA1.1 (DAT2)
/SDHC_D3: U1.7 (PTE4/LLWU_P2), XA1.2 (CD/DAT3)
/SD_SENSE_SW: U1.9 (PTE6), XA1.9 (DET)
/SP0: P1.A22 (PWMS_0), U1.104 (PTC1/LLWU_P6)
/SPI_MISO: P1.B31 (SPI_MISO), U1.96 (PTB17)
/SPI_MOSI: P1.A31 (SPI_MOSI), R37.2
/SPI_MOSI_r: R37.1, U1.95 (PTB16)
/SPI_SCLK: P1.B29 (SPI_SCLK), R36.2
/SPI_SCLK_r: R36.1, U1.92 (PTB11)
/SPI_SEL0: P1.A30 (SPI_SEL0), U1.91 (PTB10)
/SPI_SEL1: P1.A48 (SPI_SEL1), U1.90 (PTB9)
/SPI_SEL2: P1.A53 (SPI_SEL2), U1.89 (PTB8)
/SPI_SEL3: P1.B53 (SPI_SEL3), U1.126 (PTC19)
/SWD_CLK_MAIN: R33.2, R49.2, U1.50 (PTA0)
/SWD_CLK_MAIN_r: R33.1, U2.26 (PTC5/LLWU_P9)
/SWD_CLK_MAIN_r2: J1.12 (JTAG_TCLK/SWD_CLK), R49.1
/SWD_CLK_MBED: R52.2, U2.10 (PTA0)
/SWD_CLK_MBED_r: J1.22 (SWD_CLK_OSDA), R52.1
/SWD_DIO_MAIN: R34.2, R50.2, U1.53 (PTA3)
/SWD_DIO_MAIN_r: R34.1, U2.27 (PTC6/LLWU_P10)
/SWD_DIO_MAIN_r2: J1.13 (JTAG_TMS/SWD_DIO), R50.1
/SWD_DIO_MBED: R53.2, U2.13 (PTA3)
/SWD_DIO_MBED_r: J1.26 (SWD_DIO_OSDA), R53.1
/SYSCLKH: P1.B26 (SYSCLKH), R38.2
/SYSCLKH_r: R38.1, U1.106 (PTC3/LLWU_P7)
/UART1_RX_MAIN: R32.2, U1.119 (PTC14)
/UART1_RX_MAIN_r: R32.1, U2.25 (PTC4/LLWU_P8)
/UART1_TX_MAIN: R31.2, U1.120 (PTC15)
/UART1_TX_MAIN_r: R31.1, U2.24 (PTC3/LLWU_P7)
/UART_RX_MBED: R55.2, U2.11 (PTA1)
/UART_RX_MBED_r: J1.15 (RX_OSDA), R55.1
/UART_TX_MBED: R54.2, U2.12 (PTA2)
/UART_TX_MBED_r: J1.16 (TX_OSDA), R54.1
/USB_DM_MAIN: R28.1, U1.20 (USB0_DM)
/USB_DM_MBED: R2.1, U2.4 (USB0_DM)
/USB_DP_MAIN: R27.2, U1.19 (USB0_DP)
/USB_DP_MBED: R1.2, U2.3 (USB0_DP)
/USB_PWR_DISABLE: P1.A29 (USB_PWR_DISABLE), R45.1, U4.3 (EN)
/USB_SENSE_MAIN: R42.2, R43.1, U1.130 (PTD3)
/VOUT33_MAIN: C11.1, U1.21 (VOUT33)
/VOUT33_MBED: C2.1, U2.5 (VOUT33)
/VREGIN_MAIN: C9.1, D13.2 (A), L4.1, R42.1, U1.22 (VREGIN)
/VREGIN_MBED: C1.1, D14.2 (A), L2.1, R29.1, U2.6 (VREGIN)
/VRTCBAT: C10.1, D6.1 (K), D7.1 (K), U1.42 (VBAT)
/XTAL32_MAIN: U1.40 (XTAL32), Y2.2
/XTAL_MBED: C8.1, U2.18 (PTA19), Y1.3
GND: C1.2, C2.2, C3.2, C4.2, C5.2, C6.2, C7.2, C8.2, C9.2, C10.2, C11.2, C12.2, C13.2, C14.2, C15.2, C16.2, C17.2, C18.2, C19.2, C20.2, C21.2, C22.2, C23.2, C24.2, C25.2, D1.2 (GND), D2.1 (K), D5.1 (K), D11.2 (GND), J1.6 (GND), J1.9 (GND), J1.20 (GND), J1.25 (GND), J1.30 (GND), J1.34 (GND), J1.39 (GND), J2.5 (GND), J3.4, J4.5 (GND), L1.2, L3.2, P1.A07 (GND), P1.A11 (GND), P1.A13 (GND), P1.A17 (GND), P1.A19 (GND), P1.A21 (GND), P1.A26 (GND), P1.A27 (GND), P1.A28 (GND), P1.A32 (GND), P1.A39 (GND), P1.A41 (GND), P1.A45 (GND), P1.A47 (GND), P1.A55 (GND), P1.A57 (GND), P1.A61 (GND), P1.A63 (GND), P1.A67 (GND), P1.A69 (GND), P1.A73 (GND), P1.A75 (GND), P1.A79 (GND), P1.A81 (GND), P1.B03 (GND), P1.B04 (GND), P1.B05 (GND), P1.B06 (GND), P1.B07 (GND), P1.B11 (GND), P1.B13 (GND), P1.B17 (GND), P1.B19 (GND), P1.B21 (GND), P1.B25 (GND), P1.B27 (GND), P1.B32 (GND), P1.B39 (GND), P1.B41 (GND), P1.B45 (GND), P1.B47 (GND), P1.B55 (GND), P1.B57 (GND), P1.B61 (GND), P1.B63 (GND), P1.B67 (GND), P1.B69 (GND), P1.B73 (GND), P1.B75 (GND), P1.B79 (GND), P1.B81 (GND), R30.2, R43.2, R47.2, R56.2, R57.2, S1.2, U1.6 (VSS), U1.17 (VSS), U1.18 (VSS), U1.33 (VREFL), U1.34 (VSSA), U1.44 (VSS), U1.57 (VSS), U1.71 (VSS), U1.93 (VSS), U1.107 (VSS), U1.121 (VSS), U1.134 (VSS), U2.2 (VSS), U2.8 (VSSA), U2.16 (VSS), U2.33 (EP), U3.2 (GND), U4.2 (GND), XA1.6 (VSS), XA1.G1 (GND), XA1.G2 (GND), XA1.G3 (GND), XA1.G4 (GND), XBT1.1 (-), Y1.2 (GND), Y1.4 (GND)
unnamed: C20.1, D13.1 (K), D14.1 (K), R45.2, U4.1 (IN)
unnamed: D1.1 (ESD1), J4.4 (ID)
unnamed: D1.3 (ESD2), J4.3 (D+), R1.1
unnamed: D1.4 (ESD3), J4.2 (D-), R2.2
unnamed: D1.5 (VCC), J4.1 (VCC), L2.2
unnamed: D2.2 (A), R19.2
unnamed: D3.2 (A), R20.2
unnamed: D4.2 (A), R21.2
unnamed: D5.2 (A), R22.2
unnamed: D7.2 (A), XBT1.2 (+)
unnamed: D8.1 (K), R24.2
unnamed: D9.1 (K), R25.2
unnamed: D10.1 (K), R26.2
unnamed: D11.1 (ESD1), J2.4 (ID)
unnamed: D11.3 (ESD2), J2.3 (D+), J3.3, R27.1
unnamed: D11.4 (ESD3), J2.2 (D-), J3.2, R28.2
unnamed: D11.5 (VCC), J2.1 (VCC), J3.1, L4.2
unnamed: J2.6 (shield), L3.1
unnamed: J4.6 (shield), L1.1
unnamed: Q1.1 (G), Q2.4 (C), R57.1
unnamed: Q2.1 (C), Q2.2 (B), Q2.3 (B), R56.1
unnamed: R46.2, R47.1, U4.4 (ADJ)
unnamed: R48.1, XA1.5 (CLK)

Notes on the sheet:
Decoupling Caps - Place 0.1UF caps near VDD pads.
OX40N Connector
mbed Controller (KL26Z)
Main Controller (K22F)
OCX164 Connector
This pin is used for sensing when a powered USB connection is made.
TVS module to prevent ESD blowing up USB and VIN.
MicroUSB-AB
MicroSD Card Connector
Main USB
mbed USB
Main Reset
mbed Reset
Reset is normally high. Pulled low when USB is disconnected, button is pressed, or via SWD.
Reset is normally high. Pulled low by mbed, OX26, button is pressed, or via SWD/JTAG.
SYS LED B
SYS LED R
SYS LED G
OX40N connector is compatible with a Raspberry Pi 26 or 40 pin connector. It could easily be used with other external controllers and can even power them via 5V supply and switchable 3.3V supply. It mainly provides I2C, SPI, and UART connections to the main MCU. Pins 27-40 are reserved for RMIIO co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
The OCX164 connector interfaces the main controller to a modular backplane or single board.
This MCU is only for debugging and programming the main MCU on this board. It is running the DAPLink firmware from https://github.com/mbedmicro/DAPLink to enable mbed compatibility. It is possible to put other firmware on it via the SWD connector. The interface is only to the Main MCU and USB.
This pullup prevents odd behavior from the NMI_b. NMI_b should be disabled in firmware.
USB Power
By default, USB will power the 3.3V supply on the board. If a powered backplane is connected, the LDO is disabled by pulling the EN pin low.
Series Resistors
I2C Pull-up Resistors
DNP if using KL27Z version. (crystal-free USB operation)
Isolation Resistors
VCC Isolation
PWR LED G
USB AUX
5V Protection
This is based on the RPi HAT spec. It prevents bad things happening if USB is plugged into a Pi with a different 5V.

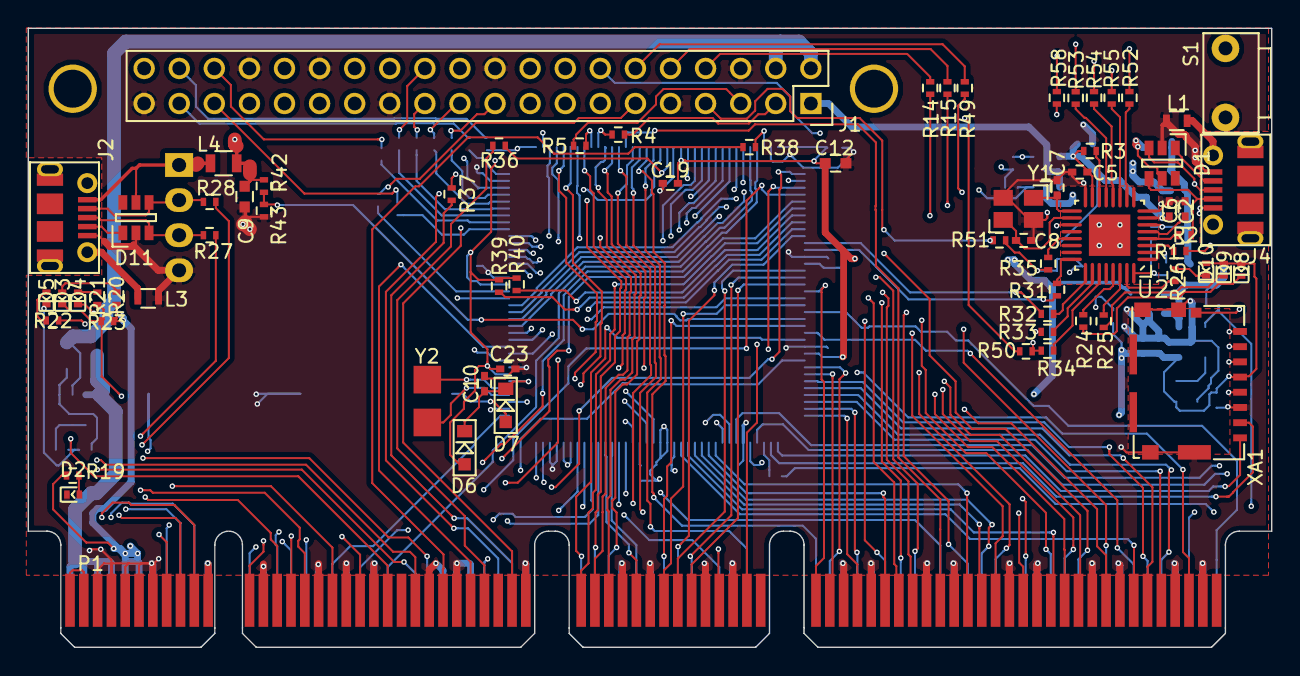
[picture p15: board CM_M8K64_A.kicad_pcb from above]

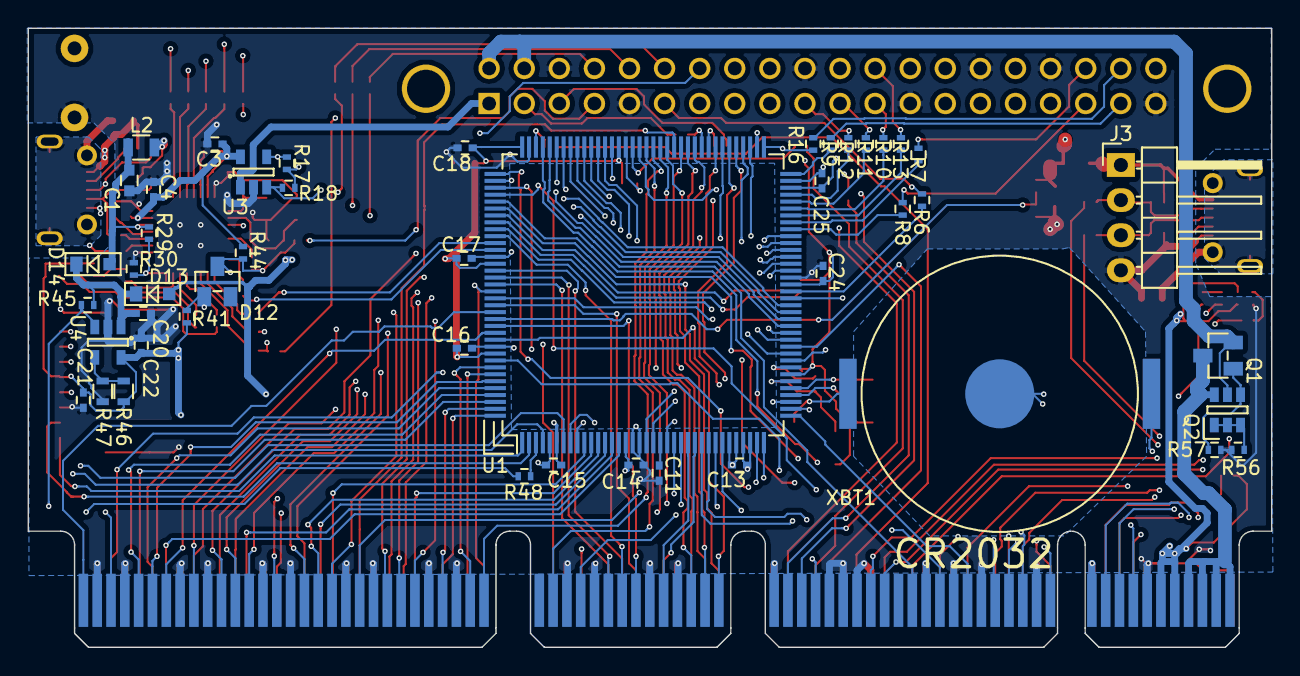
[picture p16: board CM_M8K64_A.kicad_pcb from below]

Board: 4 copper layers, 90.0 x 44.8 mm, 117 parts (47 on the bottom side), 197 nets.

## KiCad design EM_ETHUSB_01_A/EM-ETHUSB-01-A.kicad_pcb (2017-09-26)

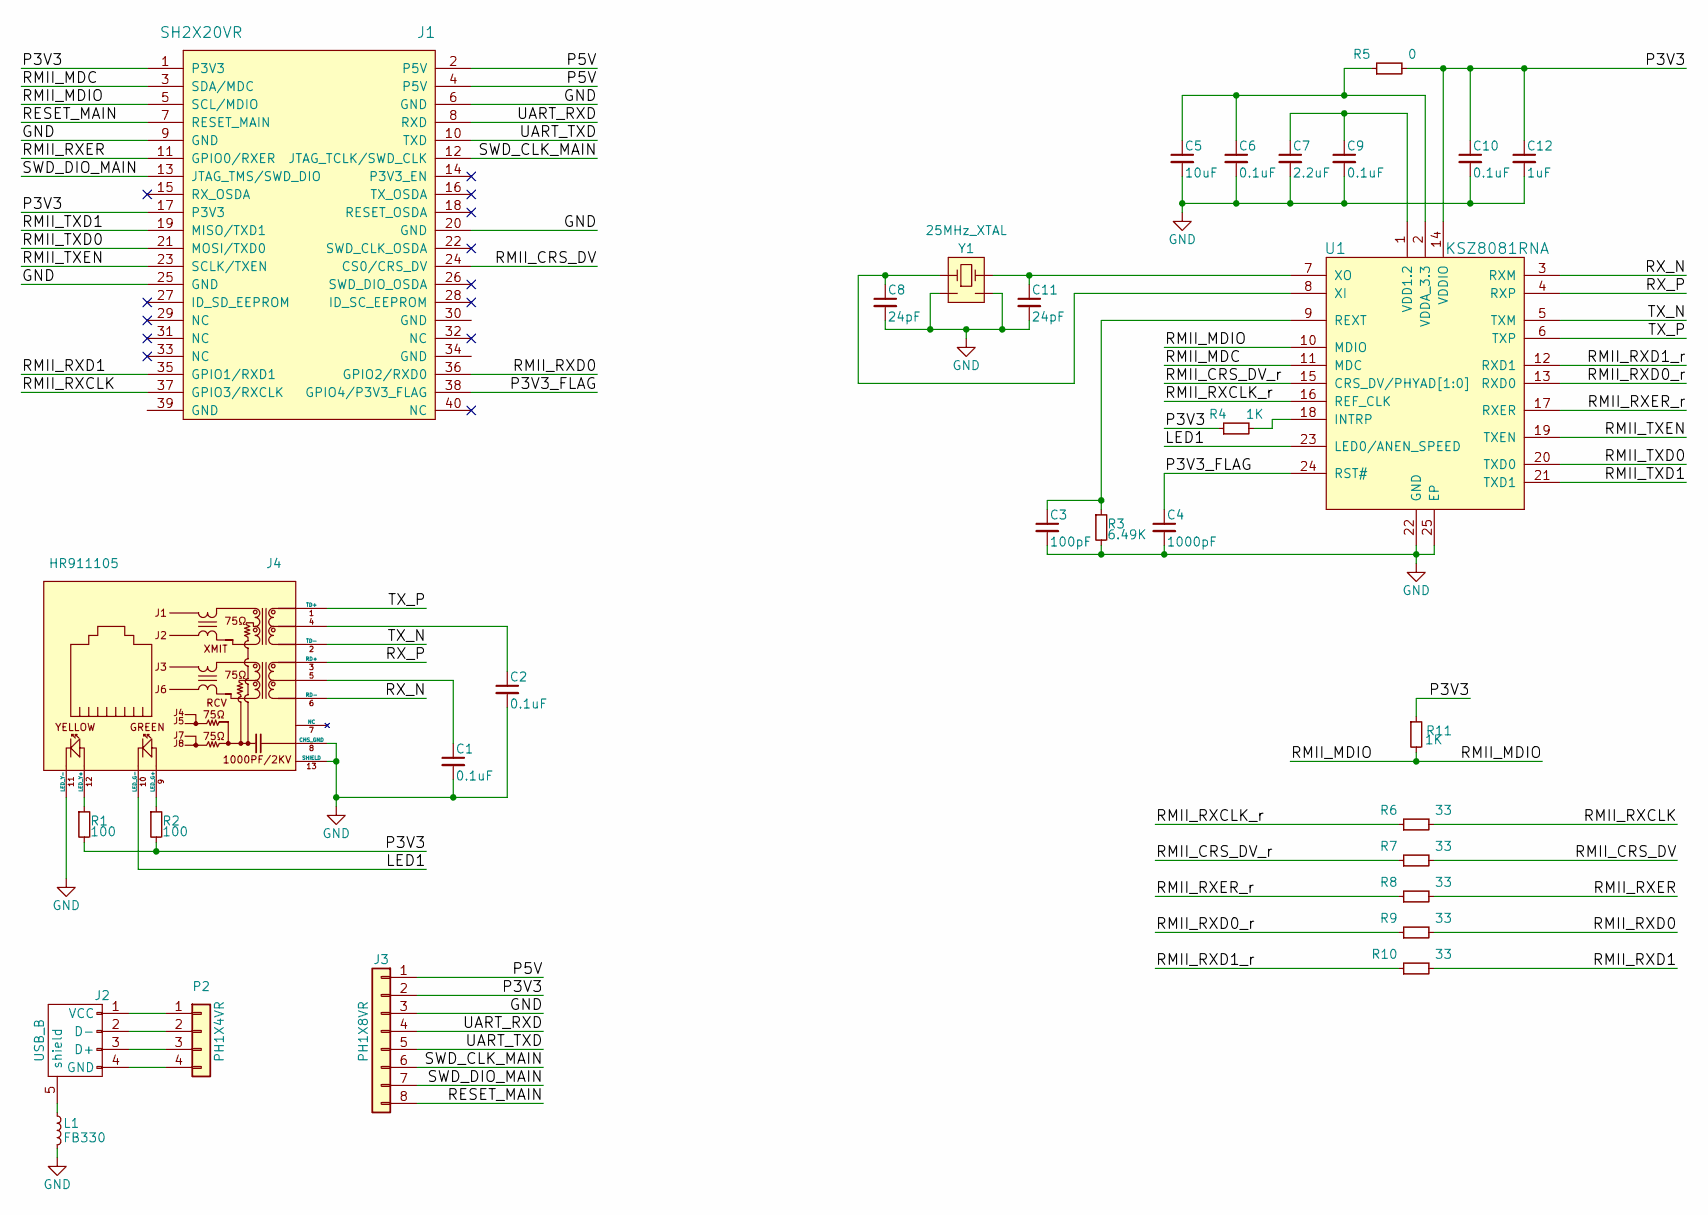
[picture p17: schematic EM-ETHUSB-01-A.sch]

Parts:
C1, C2, C6, C9, C10: 0.1uF; C_0402; MPN GRM155R71H104ME14D
C3: 100pF; C_0402; MPN GRM1555C1H101JA01D
C4: 1000pF; C_0402; MPN GRM155R71H102KA01D
C5: 10uF; C_0603; MPN GRM188R60J106KE47D
C7: 2.2uF; C_0402; MPN GRM155R60J225KE95D
C8, C11: 24pF; C_0402; MPN GRM1555C1H240GA01D
C12: 1uF; C_0402; MPN GRM155R60J105KE19D
J1: SH2X20VR; OX40_W_PI_HOLE; MPN PREC020DAAN-RC
J2: USB_B; Molex_67068-003_Full_Size_USB; MPN 670688000
J3: PH1X8VR; Pin_Header_Straight_1x08; MPN DNP
J4: HR911105; HR911105A; MPN HR911105
L1: FB330; R_0603; MPN MPZ1608S331ATA00
P2: PH1X4VR; Pin_Header_Straight_1x04; MPN M20-9990445
R1, R2: 100; R_0402; MPN RC0402JR-07100RL
R3: 6.49K; R_0402; MPN RC0402FR-076K49L
R4, R11: 1K; R_0402; MPN RC0402JR-071KL
R5: 0; R_0402; MPN RC0402JR-070RL
R6, R7, R8, R9, R10: 33; R_0402; MPN RC0402JR-0733RL
U1: KSZ8081RNA; QFN-24-1EP_4x4mm_Pitch0.5mm; MPN KSZ8081RNACA-TR
Y1: 25MHz_XTAL; XTAL3_2X2_5; MPN ABM8G-25.000MHZ-18-D2Y-T

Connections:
/LED1: J4.10 (LED_G-), U1.23 (LED0/ANEN_SPEED)
/P3V3: C10.1, C12.1, J1.1 (P3V3), J1.17 (P3V3), J3.2, R1.2, R2.2, R4.1, R5.2, R11.1, U1.14 (VDDIO)
/P3V3_FLAG: C4.1, J1.38 (GPIO4/P3V3_FLAG), U1.24 (RST#)
/P5V: J1.2 (P5V), J1.4 (P5V), J3.1
/RESET_MAIN: J1.7 (RESET_MAIN), J3.8
/RMII_CRS_DV: J1.24 (CS0/CRS_DV), R7.2
/RMII_CRS_DV_r: R7.1, U1.15 (CRS_DV/PHYAD[1:0])
/RMII_MDC: J1.3 (SDA/MDC), U1.11 (MDC)
/RMII_MDIO: J1.5 (SCL/MDIO), R11.2, U1.10 (MDIO)
/RMII_RXCLK: J1.37 (GPIO3/RXCLK), R6.2
/RMII_RXCLK_r: R6.1, U1.16 (REF_CLK)
/RMII_RXD0: J1.36 (GPIO2/RXD0), R9.2
/RMII_RXD0_r: R9.1, U1.13 (RXD0)
/RMII_RXD1: J1.35 (GPIO1/RXD1), R10.2
/RMII_RXD1_r: R10.1, U1.12 (RXD1)
/RMII_RXER: J1.11 (GPIO0/RXER), R8.2
/RMII_RXER_r: R8.1, U1.17 (RXER)
/RMII_TXD0: J1.21 (MOSI/TXD0), U1.20 (TXD0)
/RMII_TXD1: J1.19 (MISO/TXD1), U1.21 (TXD1)
/RMII_TXEN: J1.23 (SCLK/TXEN), U1.19 (TXEN)
/RX_N: J4.6 (RD-), U1.3 (RXM)
/RX_P: J4.3 (RD+), U1.4 (RXP)
/SWD_CLK_MAIN: J1.12 (JTAG_TCLK/SWD_CLK), J3.6
/SWD_DIO_MAIN: J1.13 (JTAG_TMS/SWD_DIO), J3.7
/TX_N: J4.2 (TD-), U1.5 (TXM)
/TX_P: J4.1 (TD+), U1.6 (TXP)
/UART_RXD: J1.8 (RXD), J3.4
/UART_TXD: J1.10 (TXD), J3.5
GND: C1.2, C2.2, C3.2, C4.2, C5.2, C6.2, C7.2, C8.2, C9.2, C10.2, C11.2, C12.2, J1.6 (GND), J1.9 (GND), J1.20 (GND), J1.25 (GND), J3.3, J4.8 (CHS_GND), J4.11 (LED_Y-), J4.13 (SHIELD), L1.2, R3.2, U1.22 (GND), U1.25 (EP), Y1.2 (GND), Y1.4 (GND)
unnamed: C1.1, J4.5
unnamed: C2.1, J4.4
unnamed: C3.1, R3.1, U1.9 (REXT)
unnamed: C5.1, C6.1, R5.1, U1.2 (VDDA_3.3)
unnamed: C7.1, C9.1, U1.1 (VDD1.2)
unnamed: C8.1, U1.8 (XI), Y1.1
unnamed: C11.1, U1.7 (XO), Y1.3
unnamed: J2.1 (VCC), P2.1
unnamed: J2.2 (D-), P2.2
unnamed: J2.3 (D+), P2.3
unnamed: J2.4 (GND), P2.4
unnamed: J2.5 (shield), L1.1
unnamed: J4.9 (LED_G+), R2.1
unnamed: J4.12 (LED_Y+), R1.1
unnamed: R4.2, U1.18 (INTRP)

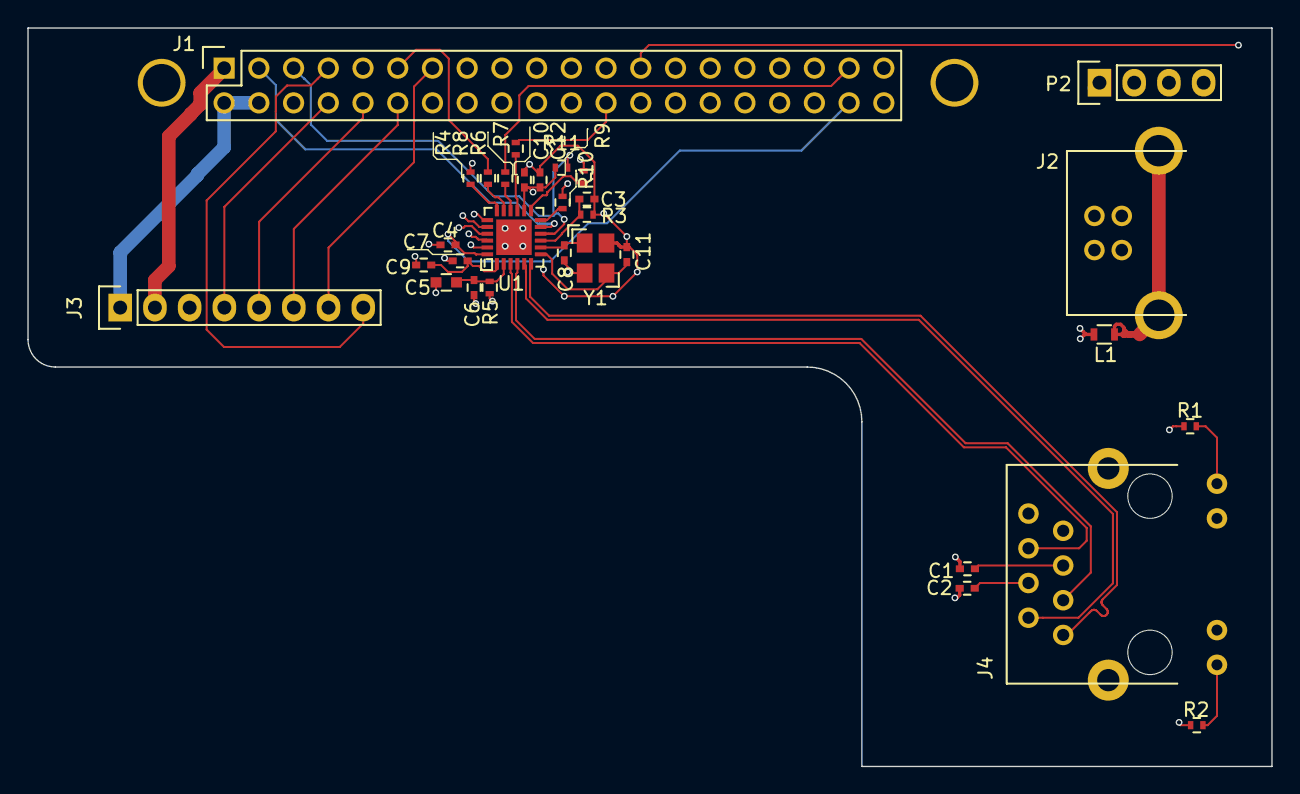
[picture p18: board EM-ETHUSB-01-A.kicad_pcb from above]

Board: 4 copper layers, 91.0 x 54.0 mm, 31 parts (0 on the bottom side), 44 nets.

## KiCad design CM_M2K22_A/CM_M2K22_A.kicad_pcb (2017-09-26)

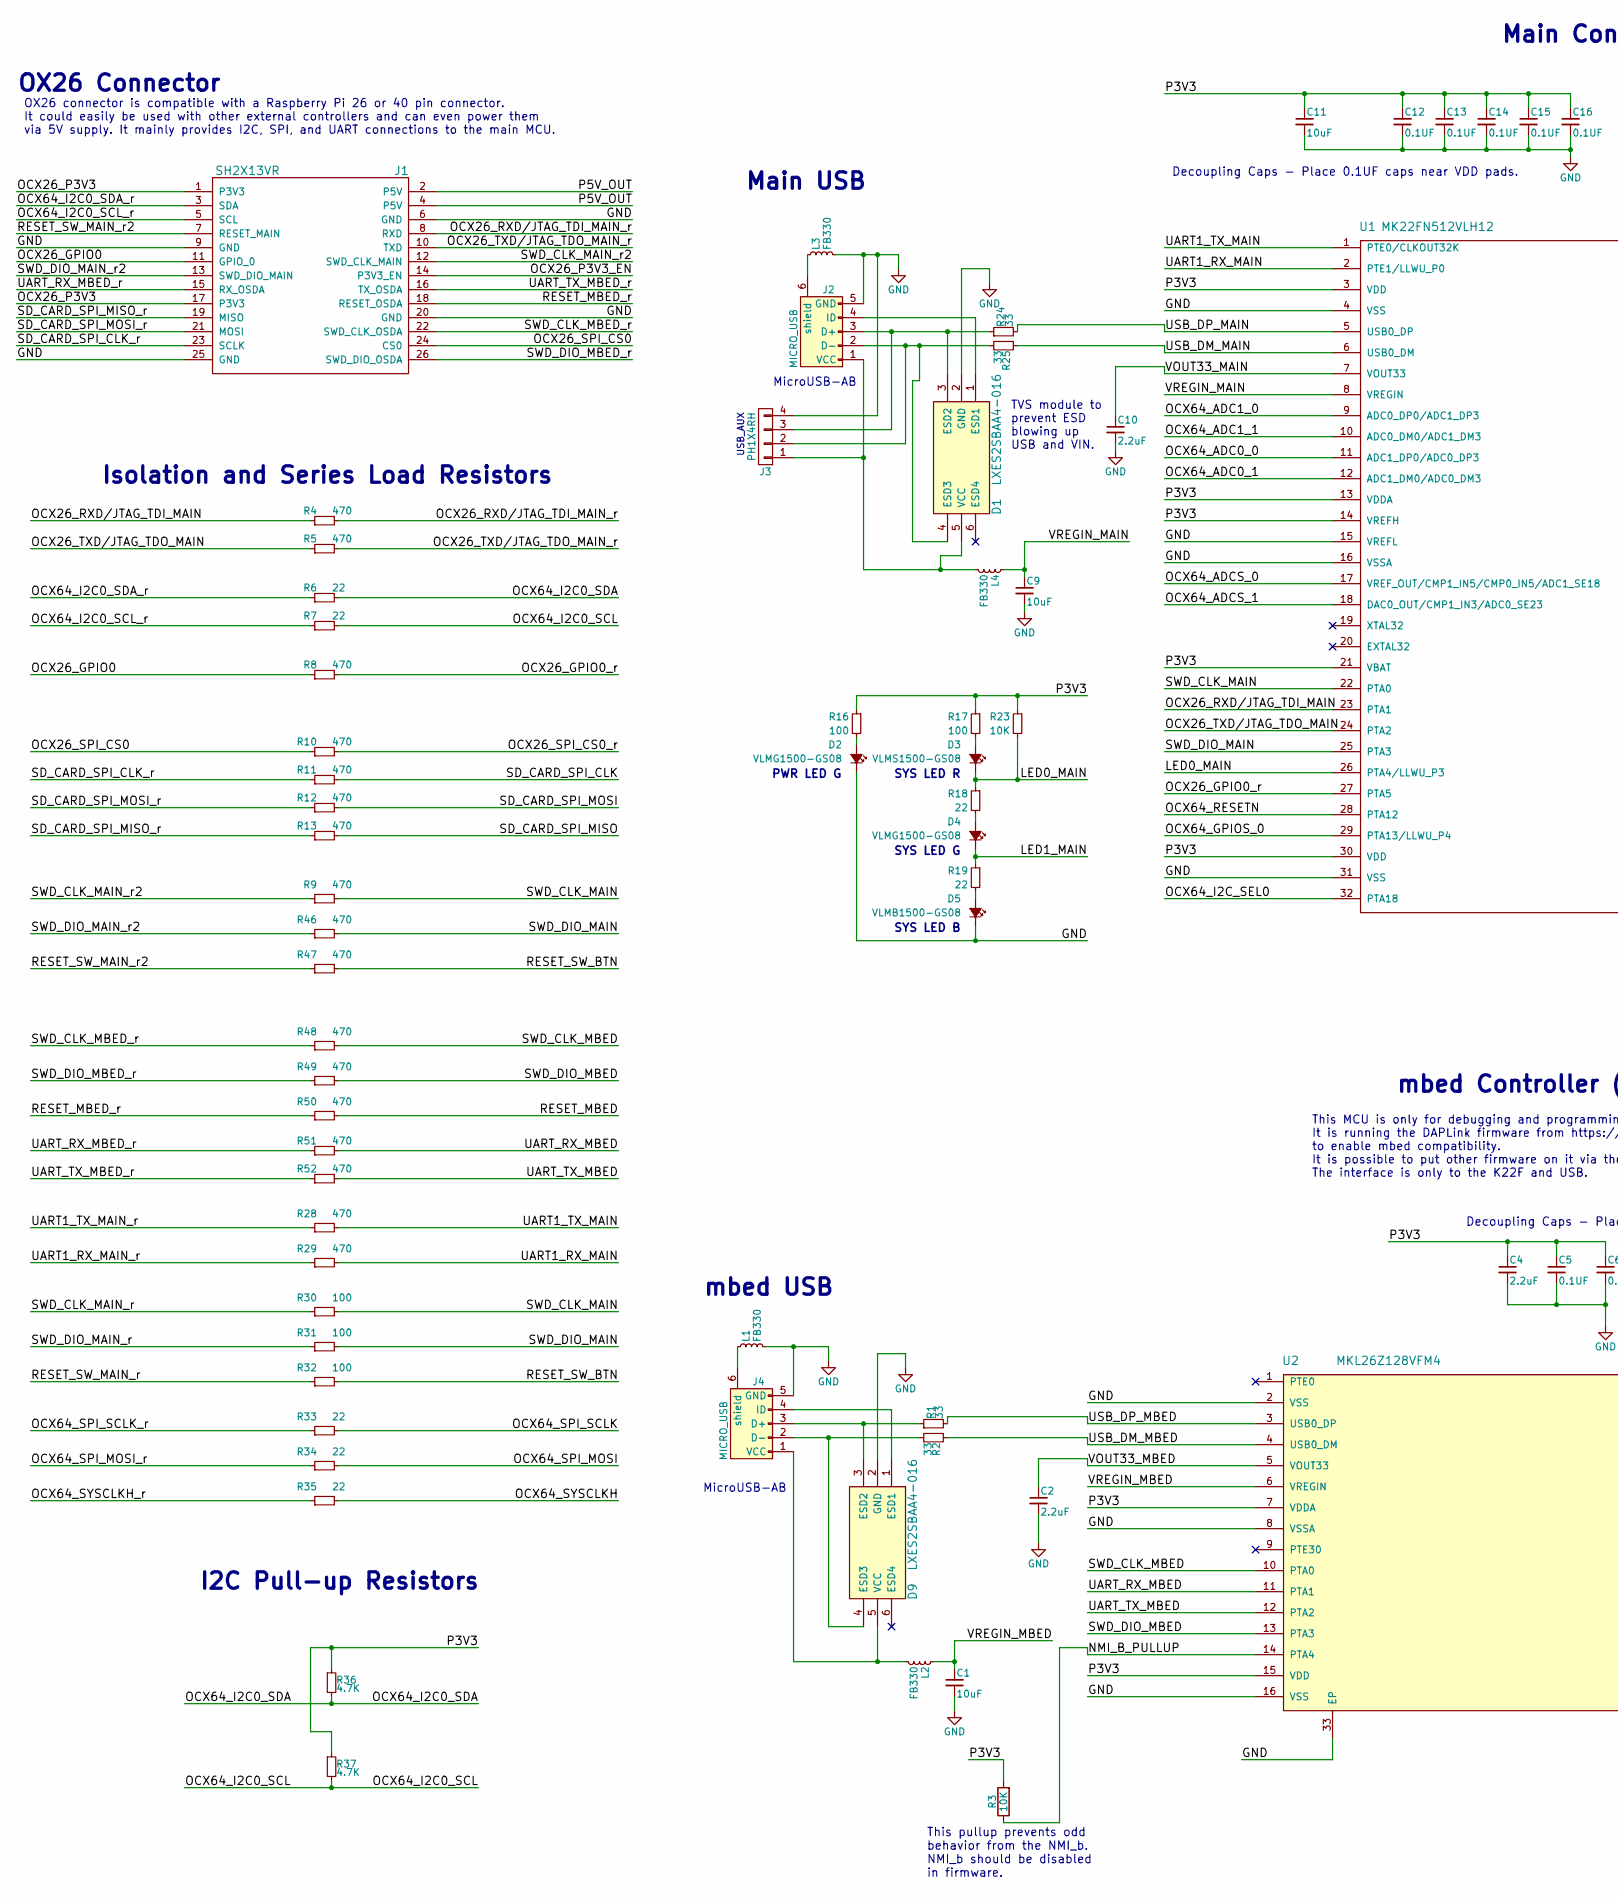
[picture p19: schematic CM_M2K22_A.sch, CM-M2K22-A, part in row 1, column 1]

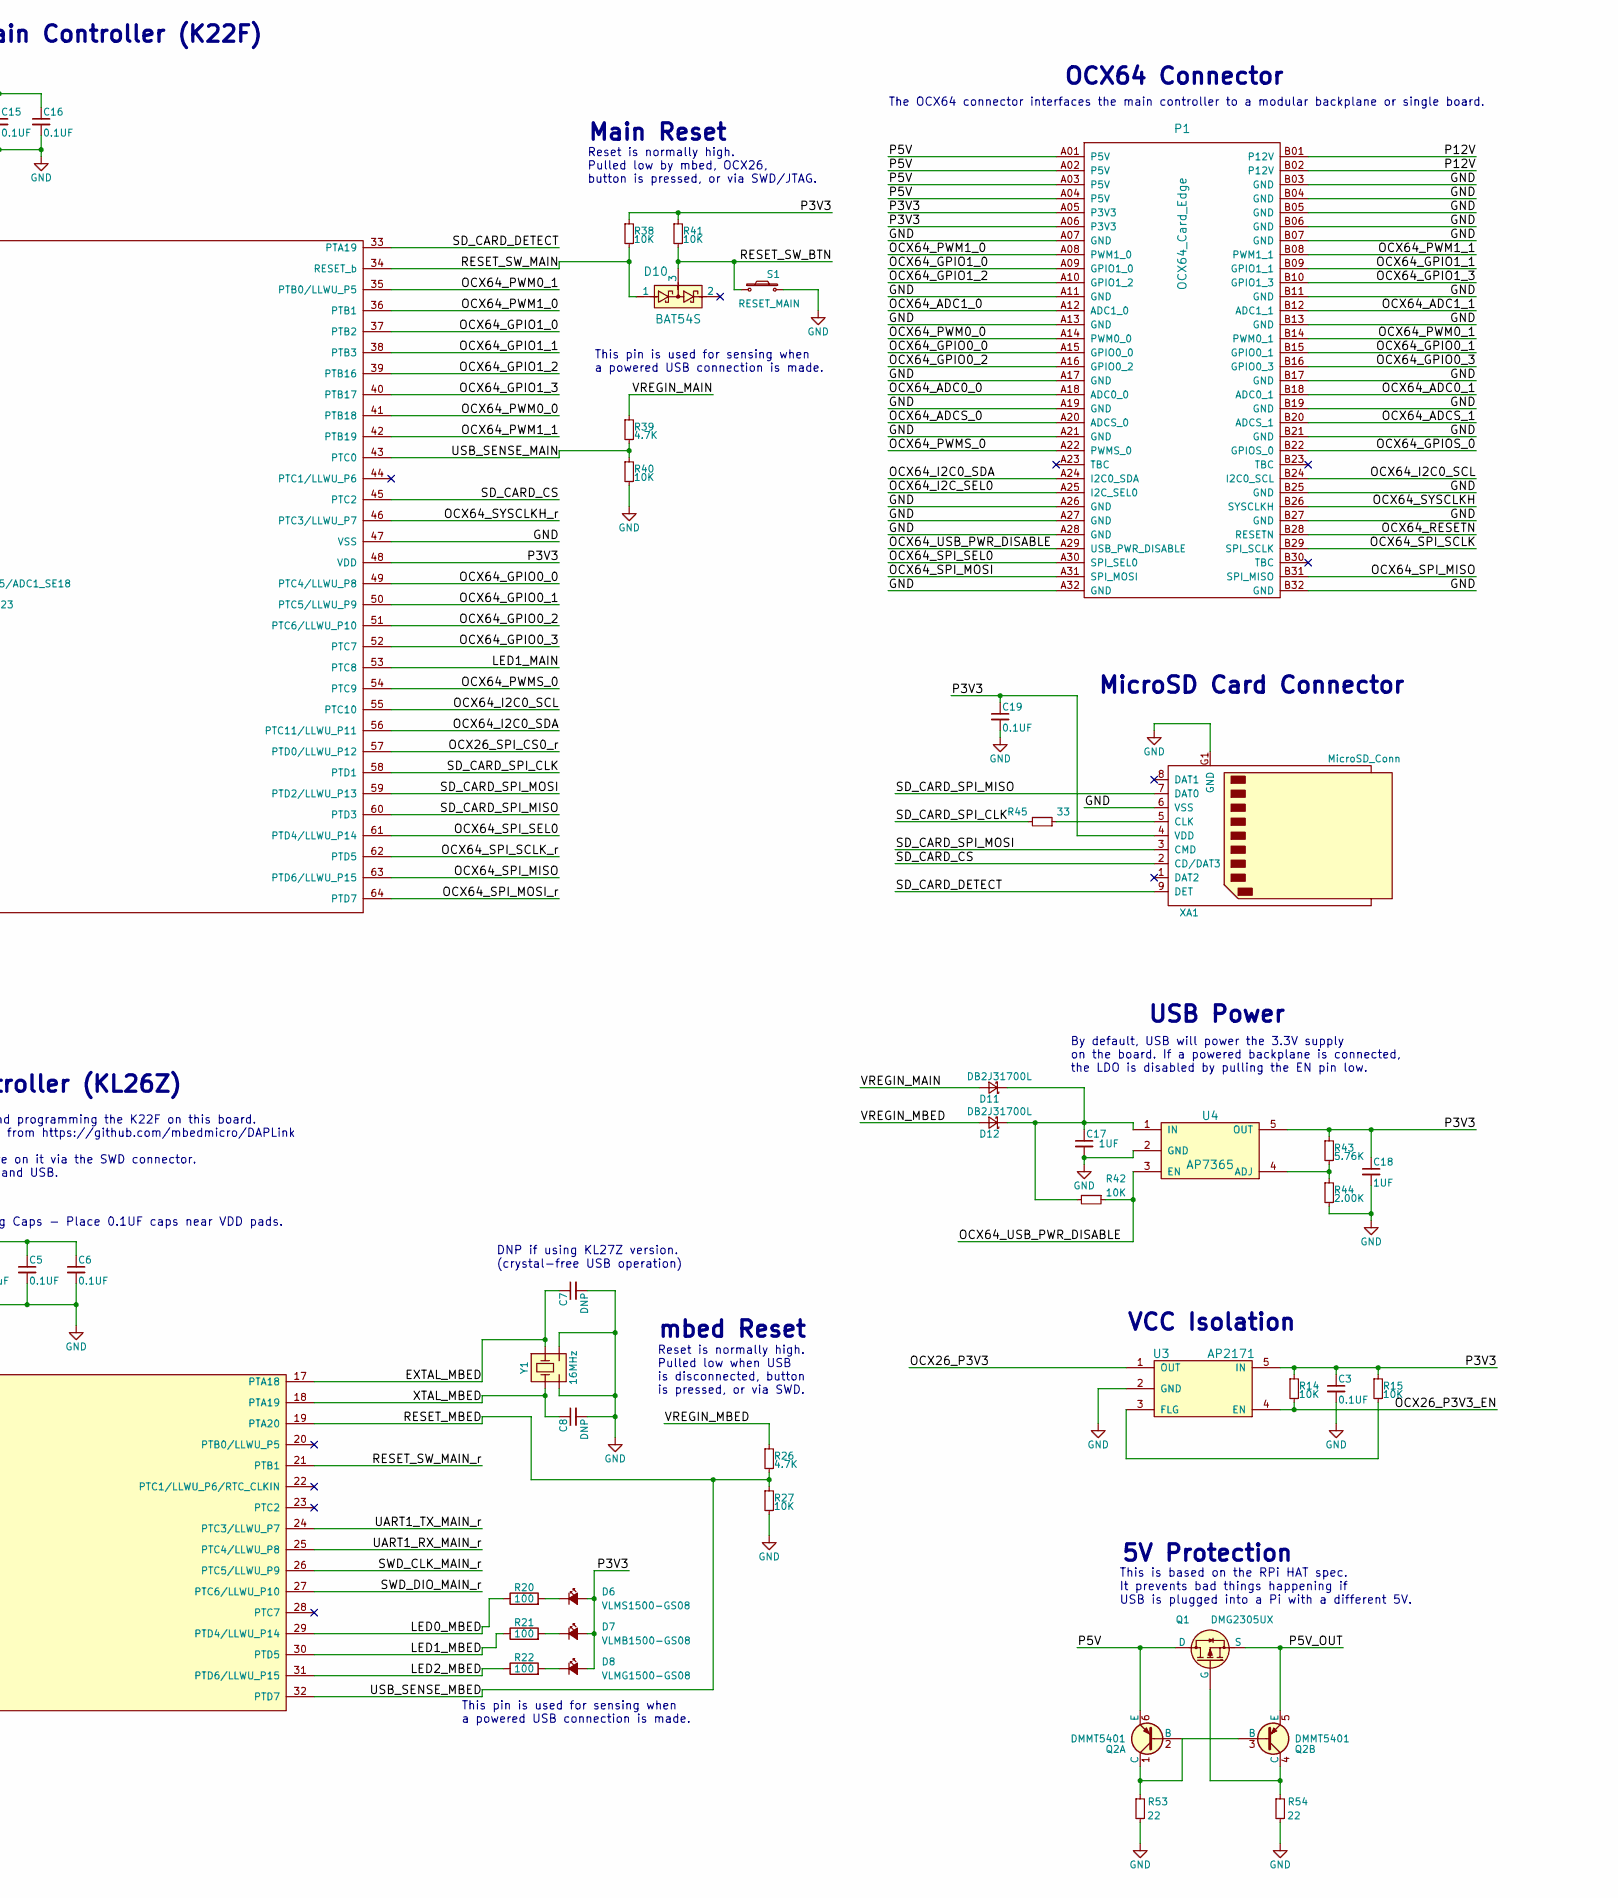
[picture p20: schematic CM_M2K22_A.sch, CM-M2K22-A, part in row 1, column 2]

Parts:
C1, C9, C11: 10uF; C_0603; MPN GRM188R60J106KE47D
C2, C4, C10: 2.2uF; C_0402; MPN GRM155R60J225KE95D
C3, C5, C6, C12, C13, C14, C15, C16, C19: 0.1UF; C_0402; MPN GRM155R71H104ME14D
C7, C8: DNP; C_0402; MPN DNP
C17, C18: 1UF; C_0402; MPN GRM155R60J105KE19D
D1, D9: LXES2SBAA4-016; SOT-23-6; MPN LXES2SBAA4-016
D2, D4, D8: VLMG1500-GS08; LED_0402; MPN VLMG1500-GS08
D3, D6: VLMS1500-GS08; LED_0402; MPN VLMS1500-GS08
D5, D7: VLMB1500-GS08; LED_0402; MPN VLMB1500-GS08
D10: BAT54S; SOT-23; MPN BAT54S,215
D11, D12: DB2J31700L; SC-90A; MPN DB2J31700L
J1: SH2X13VR; OCX26_w_1_Mounting_Hole; MPN PPPC132LFBN-RC
J2, J4: MICRO_USB; Micro_USB_Molex_105017-0001; MPN 1050170001
J3: PH1X4RH; Pin_Header_Angled_1x04; MPN DNP
L1, L3: FB330; R_0603; MPN MPZ1608S331ATA00
L2, L4: FB330; R_0805; MPN MPZ2012S331AT000
P1: OCX64_Card_Edge; MPN DNP
Q1: DMG2305UX; SOT-23; MPN DMG2305UX-13
Q2: DMMT5401; SOT-23-6; MPN DMMT5401-7-F
R1, R2, R24, R25, R45: 33; R_0402; MPN RC0402JR-0733RL
R3, R14, R15, R23, R27, R38, R40, R41, R42: 10K; R_0402; MPN RC0402JR-0710KL
R4, R5, R8, R9, R10, R11, R12, R13, R28, R29, R46, R47, R48, R49, R50, R51, R52: 470; R_0402; MPN RC0402JR-07470RL
R6, R7, R18, R19, R33, R34, R35, R53, R54: 22; R_0402; MPN RC0402JR-0722RL
R16, R17, R20, R21, R22, R30, R31, R32: 100; R_0402; MPN RC0402JR-07100RL
R26, R36, R37, R39: 4.7K; R_0402; MPN RC0402JR-074K7L
R43: 5.76K; R_0603; Tolerance 1%; MPN RC0603FR-075K76L
R44: 2.00K; R_0603; Tolerance 1%; MPN RC0603FR-072KL
S1: RESET_MAIN; Switch_TS-1101F_SZ_BEST; MPN TS-1101F
U1: MK22FN512VLH12; Freescale_LQFP-64; MPN MK22FN512VLH12
U2: MKL26Z128VFM4; QFN32_w_TP_FS; MPN MKL26Z128VFM4
U3: AP2171; SOT-23-5; MPN AP2171WG-7
U4: AP7365; SOT-23-5; MPN AP7365-WG-7
XA1: MicroSD_Conn; 1051620101; MPN 1051620101
Y1: 16MHz; XTAL3_2X2_5; MPN FA-238 16.0000MB-K3

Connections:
/EXTAL_MBED: C7.1, U2.17 (PTA18), Y1.1
/LED0_MAIN: D3.1 (K), R18.1, R23.2, U1.26 (PTA4/LLWU_P3)
/LED0_MBED: R20.1, U2.29 (PTD4/LLWU_P14)
/LED1_MAIN: D4.1 (K), R19.1, U1.53 (PTC8)
/LED1_MBED: R21.1, U2.30 (PTD5)
/LED2_MBED: R22.1, U2.31 (PTD6/LLWU_P15)
/NMI_B_PULLUP: R3.1, U2.14 (PTA4)
/OCX26_GPIO0: J1.11 (GPIO_0), R8.1
/OCX26_GPIO0_r: R8.2, U1.27 (PTA5)
/OCX26_P3V3: J1.1 (P3V3), J1.17 (P3V3), U3.1 (OUT)
/OCX26_P3V3_EN: J1.14 (P3V3_EN), R14.2, U3.4 (EN)
/OCX26_RXD/JTAG_TDI_MAIN: R4.1, U1.23 (PTA1)
/OCX26_RXD/JTAG_TDI_MAIN_r: J1.8 (RXD), R4.2
/OCX26_SPI_CS0: J1.24 (CS0), R10.1
/OCX26_SPI_CS0_r: R10.2, U1.57 (PTD0/LLWU_P12)
/OCX26_TXD/JTAG_TDO_MAIN: R5.1, U1.24 (PTA2)
/OCX26_TXD/JTAG_TDO_MAIN_r: J1.10 (TXD), R5.2
/OCX64_ADC0_0: P1.A18 (ADC0_0), U1.11 (ADC1_DP0/ADC0_DP3)
/OCX64_ADC0_1: P1.B18 (ADC0_1), U1.12 (ADC1_DM0/ADC0_DM3)
/OCX64_ADC1_0: P1.A12 (ADC1_0), U1.9 (ADC0_DP0/ADC1_DP3)
/OCX64_ADC1_1: P1.B12 (ADC1_1), U1.10 (ADC0_DM0/ADC1_DM3)
/OCX64_ADCS_0: P1.A20 (ADCS_0), U1.17 (VREF_OUT/CMP1_IN5/CMP0_IN5/ADC1_SE18)
/OCX64_ADCS_1: P1.B20 (ADCS_1), U1.18 (DAC0_OUT/CMP1_IN3/ADC0_SE23)
/OCX64_GPIO0_0: P1.A15 (GPIO0_0), U1.49 (PTC4/LLWU_P8)
/OCX64_GPIO0_1: P1.B15 (GPIO0_1), U1.50 (PTC5/LLWU_P9)
/OCX64_GPIO0_2: P1.A16 (GPIO0_2), U1.51 (PTC6/LLWU_P10)
/OCX64_GPIO0_3: P1.B16 (GPIO0_3), U1.52 (PTC7)
/OCX64_GPIO1_0: P1.A09 (GPIO1_0), U1.37 (PTB2)
/OCX64_GPIO1_1: P1.B09 (GPIO1_1), U1.38 (PTB3)
/OCX64_GPIO1_2: P1.A10 (GPIO1_2), U1.39 (PTB16)
/OCX64_GPIO1_3: P1.B10 (GPIO1_3), U1.40 (PTB17)
/OCX64_GPIOS_0: P1.B22 (GPIOS_0), U1.29 (PTA13/LLWU_P4)
/OCX64_I2C0_SCL: P1.B24 (I2C0_SCL), R7.2, R37.2, U1.55 (PTC10)
/OCX64_I2C0_SCL_r: J1.5 (SCL), R7.1
/OCX64_I2C0_SDA: P1.A24 (I2C0_SDA), R6.2, R36.2, U1.56 (PTC11/LLWU_P11)
/OCX64_I2C0_SDA_r: J1.3 (SDA), R6.1
/OCX64_I2C_SEL0: P1.A25 (I2C_SEL0), U1.32 (PTA18)
/OCX64_PWM0_0: P1.A14 (PWM0_0), U1.41 (PTB18)
/OCX64_PWM0_1: P1.B14 (PWM0_1), U1.35 (PTB0/LLWU_P5)
/OCX64_PWM1_0: P1.A08 (PWM1_0), U1.36 (PTB1)
/OCX64_PWM1_1: P1.B08 (PWM1_1), U1.42 (PTB19)
/OCX64_PWMS_0: P1.A22 (PWMS_0), U1.54 (PTC9)
/OCX64_RESETN: P1.B28 (RESETN), U1.28 (PTA12)
/OCX64_SPI_MISO: P1.B31 (SPI_MISO), U1.63 (PTD6/LLWU_P15)
/OCX64_SPI_MOSI: P1.A31 (SPI_MOSI), R34.2
/OCX64_SPI_MOSI_r: R34.1, U1.64 (PTD7)
/OCX64_SPI_SCLK: P1.B29 (SPI_SCLK), R33.2
/OCX64_SPI_SCLK_r: R33.1, U1.62 (PTD5)
/OCX64_SPI_SEL0: P1.A30 (SPI_SEL0), U1.61 (PTD4/LLWU_P14)
/OCX64_SYSCLKH: P1.B26 (SYSCLKH), R35.2
/OCX64_SYSCLKH_r: R35.1, U1.46 (PTC3/LLWU_P7)
/OCX64_USB_PWR_DISABLE: P1.A29 (USB_PWR_DISABLE), R42.1, U4.3 (EN)
/P3V3: C3.1, C4.1, C5.1, C6.1, C11.1, C12.1, C13.1, C14.1, C15.1, C16.1, C18.1, C19.1, D6.2 (A), D7.2 (A), D8.2 (A), P1.A05 (P3V3), P1.A06 (P3V3), R3.2, R14.1, R15.1, R16.1, R17.1, R23.1, R36.1, R37.1, R38.1, R41.1, R43.1, U1.3 (VDD), U1.13 (VDDA), U1.14 (VREFH), U1.21 (VBAT), U1.30 (VDD), U1.48 (VDD), U2.7 (VDDA), U2.15 (VDD), U3.5 (IN), U4.5 (OUT), XA1.4 (VDD)
/P5V: P1.A01 (P5V), P1.A02 (P5V), P1.A03 (P5V), P1.A04 (P5V), Q1.3 (D), Q2.6 (E)
/P5V_OUT: J1.2 (P5V), J1.4 (P5V), Q1.2 (S), Q2.5 (E)
/P12V: P1.B01 (P12V), P1.B02 (P12V)
/RESET_MBED: R26.2, R27.1, R50.2, U2.19 (PTA20), U2.32 (PTD7)
/RESET_MBED_r: J1.18 (RESET_OSDA), R50.1
/RESET_SW_BTN: D10.3, R32.2, R41.2, R47.2, S1.1
/RESET_SW_MAIN: D10.1, R38.2, U1.34 (RESET_b)
/RESET_SW_MAIN_r: R32.1, U2.21 (PTB1)
/RESET_SW_MAIN_r2: J1.7 (RESET_MAIN), R47.1
/SD_CARD_CS: U1.45 (PTC2), XA1.2 (CD/DAT3)
/SD_CARD_DETECT: U1.33 (PTA19), XA1.9 (DET)
/SD_CARD_SPI_CLK: R11.2, R45.2, U1.58 (PTD1)
/SD_CARD_SPI_CLK_r: J1.23 (SCLK), R11.1
/SD_CARD_SPI_MISO: R13.2, U1.60 (PTD3), XA1.7 (DAT0)
/SD_CARD_SPI_MISO_r: J1.19 (MISO), R13.1
/SD_CARD_SPI_MOSI: R12.2, U1.59 (PTD2/LLWU_P13), XA1.3 (CMD)
/SD_CARD_SPI_MOSI_r: J1.21 (MOSI), R12.1
/SWD_CLK_MAIN: R9.2, R30.2, U1.22 (PTA0)
/SWD_CLK_MAIN_r: R30.1, U2.26 (PTC5/LLWU_P9)
/SWD_CLK_MAIN_r2: J1.12 (SWD_CLK_MAIN), R9.1
/SWD_CLK_MBED: R48.2, U2.10 (PTA0)
/SWD_CLK_MBED_r: J1.22 (SWD_CLK_OSDA), R48.1
/SWD_DIO_MAIN: R31.2, R46.2, U1.25 (PTA3)
/SWD_DIO_MAIN_r: R31.1, U2.27 (PTC6/LLWU_P10)
/SWD_DIO_MAIN_r2: J1.13 (SWD_DIO_MAIN), R46.1
/SWD_DIO_MBED: R49.2, U2.13 (PTA3)
/SWD_DIO_MBED_r: J1.26 (SWD_DIO_OSDA), R49.1
/UART1_RX_MAIN: R29.2, U1.2 (PTE1/LLWU_P0)
/UART1_RX_MAIN_r: R29.1, U2.25 (PTC4/LLWU_P8)
/UART1_TX_MAIN: R28.2, U1.1 (PTE0/CLKOUT32K)
/UART1_TX_MAIN_r: R28.1, U2.24 (PTC3/LLWU_P7)
/UART_RX_MBED: R51.2, U2.11 (PTA1)
/UART_RX_MBED_r: J1.15 (RX_OSDA), R51.1
/UART_TX_MBED: R52.2, U2.12 (PTA2)
/UART_TX_MBED_r: J1.16 (TX_OSDA), R52.1
/USB_DM_MAIN: R25.1, U1.6 (USB0_DM)
/USB_DM_MBED: R2.1, U2.4 (USB0_DM)
/USB_DP_MAIN: R24.2, U1.5 (USB0_DP)
/USB_DP_MBED: R1.2, U2.3 (USB0_DP)
/USB_SENSE_MAIN: R39.2, R40.1, U1.43 (PTC0)
/VOUT33_MAIN: C10.1, U1.7 (VOUT33)
/VOUT33_MBED: C2.1, U2.5 (VOUT33)
/VREGIN_MAIN: C9.1, D11.2 (A), L4.1, R39.1, U1.8 (VREGIN)
/VREGIN_MBED: C1.1, D12.2 (A), L2.1, R26.1, U2.6 (VREGIN)
/XTAL_MBED: C8.1, U2.18 (PTA19), Y1.3
GND: C1.2, C2.2, C3.2, C4.2, C5.2, C6.2, C7.2, C8.2, C9.2, C10.2, C11.2, C12.2, C13.2, C14.2, C15.2, C16.2, C17.2, C18.2, C19.2, D1.2 (GND), D2.1 (K), D5.1 (K), D9.2 (GND), J1.6 (GND), J1.9 (GND), J1.20 (GND), J1.25 (GND), J2.5 (GND), J3.4, J4.5 (GND), L1.2, L3.2, P1.A07 (GND), P1.A11 (GND), P1.A13 (GND), P1.A17 (GND), P1.A19 (GND), P1.A21 (GND), P1.A26 (GND), P1.A27 (GND), P1.A28 (GND), P1.A32 (GND), P1.B03 (GND), P1.B04 (GND), P1.B05 (GND), P1.B06 (GND), P1.B07 (GND), P1.B11 (GND), P1.B13 (GND), P1.B17 (GND), P1.B19 (GND), P1.B21 (GND), P1.B25 (GND), P1.B27 (GND), P1.B32 (GND), R27.2, R40.2, R44.2, R53.2, R54.2, S1.2, U1.4 (VSS), U1.15 (VREFL), U1.16 (VSSA), U1.31 (VSS), U1.47 (VSS), U2.2 (VSS), U2.8 (VSSA), U2.16 (VSS), U2.33 (EP), U3.2 (GND), U4.2 (GND), XA1.6 (VSS), XA1.G1 (GND), XA1.G2 (GND), XA1.G3 (GND), XA1.G4 (GND), Y1.2 (GND), Y1.4 (GND)
unnamed: C17.1, D11.1 (K), D12.1 (K), R42.2, U4.1 (IN)
unnamed: D1.1 (ESD1), J2.4 (ID)
unnamed: D1.3 (ESD2), J2.3 (D+), J3.3, R24.1
unnamed: D1.4 (ESD3), J2.2 (D-), J3.2, R25.2
unnamed: D1.5 (VCC), J2.1 (VCC), J3.1, L4.2
unnamed: D2.2 (A), R16.2
unnamed: D3.2 (A), R17.2
unnamed: D4.2 (A), R18.2
unnamed: D5.2 (A), R19.2
unnamed: D6.1 (K), R20.2
unnamed: D7.1 (K), R21.2
unnamed: D8.1 (K), R22.2
unnamed: D9.1 (ESD1), J4.4 (ID)
unnamed: D9.3 (ESD2), J4.3 (D+), R1.1
unnamed: D9.4 (ESD3), J4.2 (D-), R2.2
unnamed: D9.5 (VCC), J4.1 (VCC), L2.2
unnamed: J2.6 (shield), L3.1
unnamed: J4.6 (shield), L1.1
unnamed: Q1.1 (G), Q2.4 (C), R54.1
unnamed: Q2.1 (C), Q2.2 (B), Q2.3 (B), R53.1
unnamed: R15.2, U3.3 (FLG)
unnamed: R43.2, R44.1, U4.4 (ADJ)
unnamed: R45.1, XA1.5 (CLK)

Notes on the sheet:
Decoupling Caps - Place 0.1UF caps near VDD pads.
OX26 Connector
mbed Controller (KL26Z)
Main Controller (K22F)
OCX64 Connector
This pin is used for sensing when a powered USB connection is made.
TVS module to prevent ESD blowing up USB and VIN.
MicroUSB-AB
MicroSD Card Connector
Main USB
mbed USB
Main Reset
mbed Reset
Reset is normally high. Pulled low when USB is disconnected, button is pressed, or via SWD.
Reset is normally high. Pulled low by mbed, OCX26, button is pressed, or via SWD/JTAG.
SYS LED B
SYS LED R
SYS LED G
OX26 connector is compatible with a Raspberry Pi 26 or 40 pin connector. It could easily be used with other external controllers and can even power them via 5V supply. It mainly provides I2C, SPI, and UART connections to the main MCU.
The OCX64 connector interfaces the main controller to a modular backplane or single board.
This MCU is only for debugging and programming the K22F on this board. It is running the DAPLink firmware from https://github.com/mbedmicro/DAPLink to enable mbed compatibility. It is possible to put other firmware on it via the SWD connector. The interface is only to the K22F and USB.
This pullup prevents odd behavior from the NMI_b. NMI_b should be disabled in firmware.
USB Power
By default, USB will power the 3.3V supply on the board. If a powered backplane is connected, the LDO is disabled by pulling the EN pin low.
I2C Pull-up Resistors
DNP if using KL27Z version. (crystal-free USB operation)
Isolation and Series Load Resistors
VCC Isolation
PWR LED G
USB_AUX
5V Protection
This is based on the RPi HAT spec. It prevents bad things happening if USB is plugged into a Pi with a different 5V.

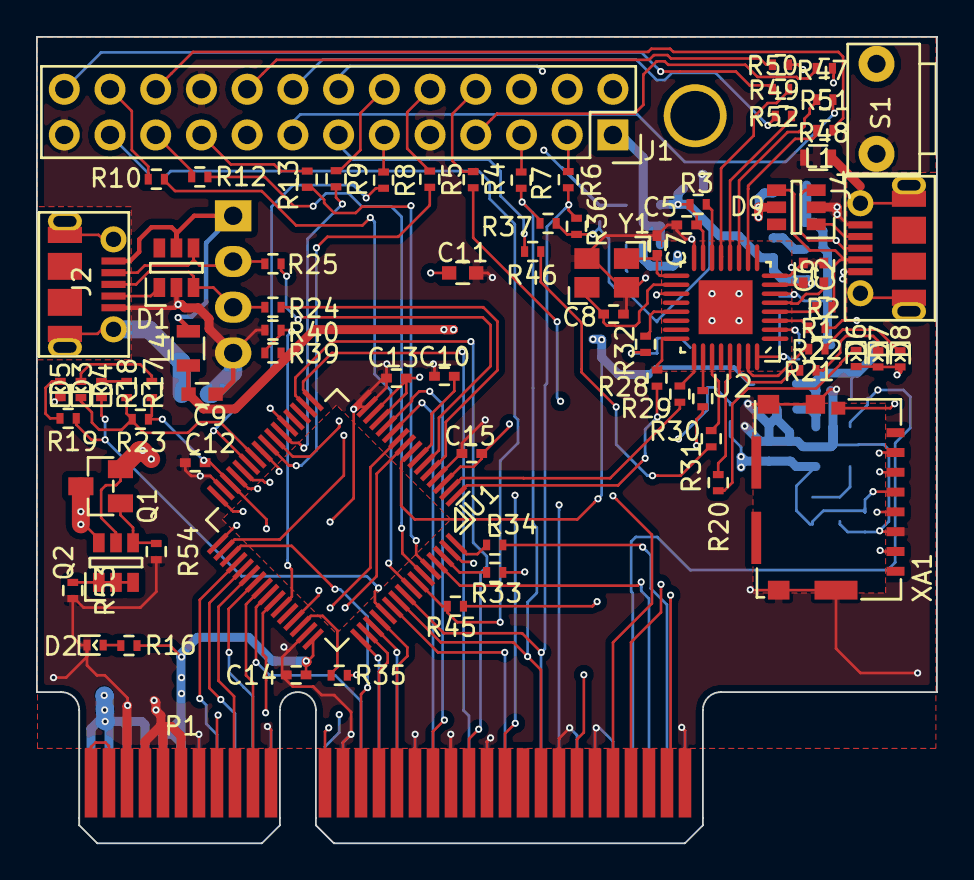
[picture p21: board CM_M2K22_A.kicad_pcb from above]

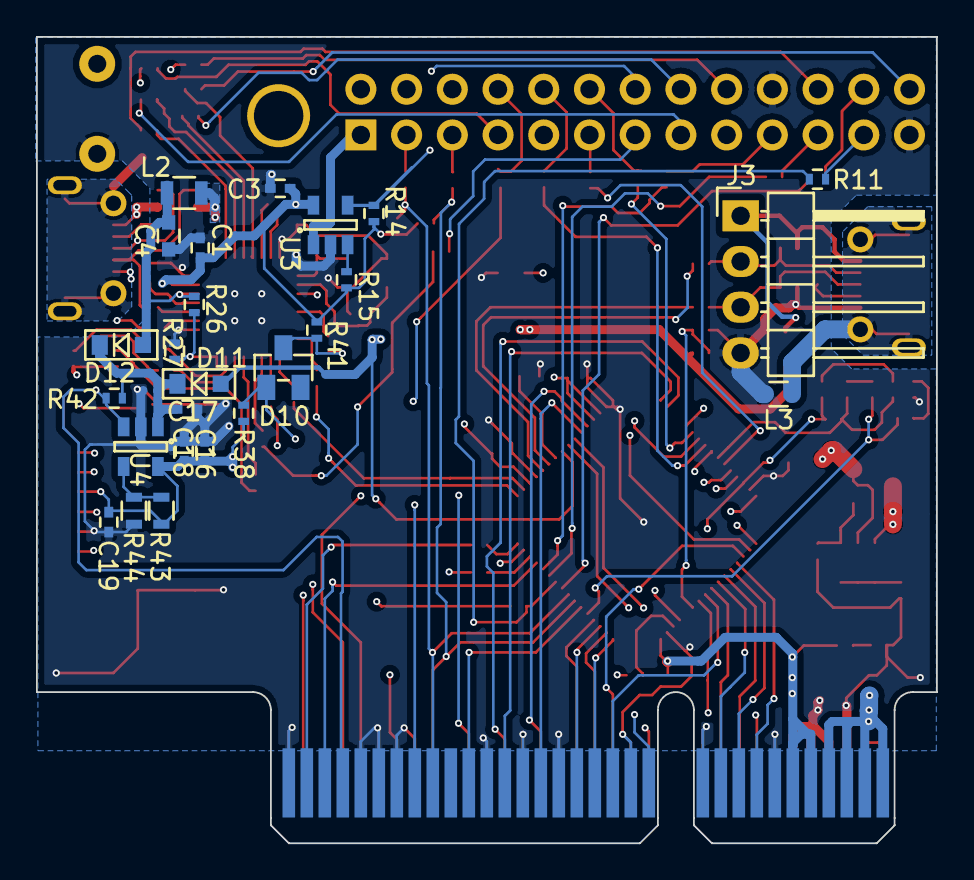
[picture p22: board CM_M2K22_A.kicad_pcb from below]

Board: 4 copper layers, 50.0 x 44.8 mm, 103 parts (25 on the bottom side), 122 nets.

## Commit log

2017-09-26 Updating Readme
    This is just a quick update on the current status and outlining the major changes in the last couple of months.
2017-09-26 Initial Commit
    This is the current production ready files (still needs final silk) for
    release.
    [CM_M2K22_A-B.Cu.gbl, CM_M2K22_A-B.Mask.gbs, CM_M2K22_A-B.Paste.gbp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]

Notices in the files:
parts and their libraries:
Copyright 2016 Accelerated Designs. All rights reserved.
